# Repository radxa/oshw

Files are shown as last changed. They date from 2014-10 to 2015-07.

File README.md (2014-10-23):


Hardware design from radxa®
=========================
Hardware work from radxa including:

* Schematic in Orcad and PDF file format
* PCB file
* Gerber file
* Bill of material(BOM)

NOTE
--------
We release these hardware design file in the purpose of study and evaluation. These hardware design files, material lists etc are tested and massively produced by Radxa Limited and proven working but we can not guarantee it works under other manufacturing environment. Radxa Limited does not take responsibility of the loss or risk of using these files. It's absolutely no WARRANTY.

LICENSE
----------


These files are licensed under a [Creative Commons Attribution 4.0 International License](http://creativecommons.org/licenses/by/4.0/), you can use it for both personal and commercial usage.

Other
-------
RADXA® is registered trade mark by Radxa Limited.

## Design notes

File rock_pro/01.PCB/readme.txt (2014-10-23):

Please open the PCB file whit the PADS9.5

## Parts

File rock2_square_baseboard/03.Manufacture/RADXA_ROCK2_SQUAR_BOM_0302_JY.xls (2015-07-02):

 | RADXA_ROCK2_SQUAR Revised: Monday, January 26, 2015
 | Index Revision: 1.0
料号 | Quantity | Reference | Part | PCB Footprint | Process | 变更内容
RADXA-01 | 1 | BT1 | BAT_3V | BAT_CR1220 | SMT
RADXA-02 | 12 | CT3,CT4,CT5,CT6,C2,C21,C7,C9,C12,C75,C94,C104 | 106（C,10UF,0805） | C0805 | SMT
RADXA-04 | 4 | CT1,C1,C45,C122 | 226(C,22UF,0805) | C0805 | SMT
RADXA-05 | 20 | C5,C22,C23,C24,C25,C33,C41,C43,C44,C56,C57,C63,C65,C68,C91,C93,C98,C100,C102,C73 | 475(C,4.7UF,0603) | C0603 | SMT
RADXA-08 | 10 | C4,C17,C18,C36,C58,C60,C61,C67,C116,C32 | 105(C.1UF,0402) | C0402 | SMT
RADXA-11 | 44 | CB1,CB2,CB3,CB4,CB5,CB6,CB7,CB8,C8,CB9,C10,C11,C13,C15,C19,C20,C26,C27,C28,C31,C34,C35,C37,C40,C42,C46,C53,C59,C62,C70,C71,C72,C76,C77,C78,C92,C95,C99,C101,C103,C105,C121,C113,C119 | 104(C,100nF,0402) | C0402 | SMT
RADXA-12 | 11 | C6,C48,C49,C50,C64,C66,C69,C108,C109,C110,C111 | 103(C,10nF,0402) | C0402 | SMT
RADXA-13 | 3 | C55,C82,C84 | 8pF(C,8pF,0402) | C0402 | SMT
RADXA-15 | 1 | C120 | 102(C,1nF,0402) | C0402 | SMT
RADXA-16 | 1 | C14 | 12P(C.12pF,0402) | C0402 | SMT
RADXA-21 | 3 | C47,C51,C52 | 100pF(C,100pF,0402) | C0402 | SMT
RADXA-22 | 4 | C29,C30,C117,C118 | 22P(C,22pF,0402) | C0402 | SMT
RADXA-26 | 1 | C3 | 47pF(C,47pF,0402) | C0402 | SMT
RADXA-29 | 9 | D1,D3,D4,D5,D14,D15,D16,D17,D18 | 1N4148 | SOD523 | SMT
RADXA-30 | 1 | D8 | LED_RED | D0603 | SMT
RADXA-31 | 1 | D7 | 1N5819 | SOD123 | SMT
RADXA-32 | 2 | D13,D10 | LED_BLUE | D0603 | SMT
RADXA-33 | 1 | D9 | LED_GREEN | D0603 | SMT
RADXA-38 | 14 | ED1,ED2,ED3,ED4,ED5,ED8,ED11,ED14,ED15,ED16,ED17,ED18,ED19,ED20 | ESD9B5V LESD8D5.0CT5G | ESD0402 | SMT
RADXA-40 | 1 | F1 | FUSE_3A | 1206-A | SMT
RADXA-41 | 1 | IR1 | FT-009(红外接收头) | TO92ECB | DIP
RADXA-42 | 1 | JD1 | USB_HOST | USB-AF | DIP
RADXA-43 | 1 | J3 | AV3-8.4-14 | PJ-342D | SMT
RADXA-45 | 1 | J1 | DC_PORT | DC-44 | DIP
RADXA-46 | 1 | J2 | MICROUSB_6.4 | MICROUSB_DIP | SMT
RADXA-47 | 1 | ANT1 | SMA | SMA_WIFI | DIP
RADXA-48 | 1 | J10 | TF_SD_SOCKET | MICROSD_SLOT | SMT
RADXA-49 | 1 | J14 | CON4 | CON4 | DIP
RADXA-50 | 1 | J13 | HEADER 20x2_2.5MM | CON_40 | DIP
RADXA-53 | 1 | J4 | FPC24P0R5 | FPC24P0R5 | SMT
RADXA-54 | 1 | J9 | FPC05P6_TOP | FPC05P6 | SMT
RADXA-55 | 1 | J8 | DLT1160 | DLT1160 | DIP
RADXA-58 | 4 | L2,L10,L11,L12 | CHOKE CM14 | USB_2012_900T | SMT
RADXA-62 | 6 | FB3,FB4,L6,L8,L9,FB7 | BLM18PG181SN1 | L0603 | SMT
RADXA-67 | 4 | Q11,Q12,Q2,Q4 | MMBT3904/2N3904 | SOT-23 | SMT
RADXA-69 | 3 | Q7,Q8,Q13 | WNM2021/2SK3018 | SOT-23 | SMT
RADXA-71 | 24 | R3,R8,R11,R12,R14,R16,R18,R23,R24,R30,R36,R57,R58,R61,R66,R67,R68,R72,R137,R138,R141,R155,R47,R15 | 10K-5% | R0402 | SMT
RADXA-72 | 6 | R25,R27,R31,R139,R161,R162 | 47K-5% | R0402 | SMT
RADXA-73 | 8 | R7,R35,R111,R142,R144,R145,R146,R157 | 4.7K-5% | R0402 | SMT
RADXA-74 | 1 | R140 | 1M-5% | R0402 | SMT
RADXA-75 | 10 | R2,R9,R10,R13,R34,R69,R70,R71,R153,R156 | 100K-5% | R0402 | SMT
RADXA-76 | 5 | R19,R46,R79,R150,R163 | 1K-5% | R0402 | SMT
RADXA-77 | 9 | R33,R114,R154,R53,R54,R115,R116,R131,R133 | 680R-5% | R0402 | SMT
RADXA-78 | 2 | R87,R109 | 100R-5% | R0402 | SMT
RADXA-81 | 1 | R5 | 51K-5% | R0402 | SMT
RADXA-83 | 2 | R20,R75 | 15K-5% | R0402 | SMT
RADXA-84 | 1 | R108 | 22R-5% | R0402 | SMT
RADXA-88 | 10 | R49,R52,R62,R64,R88,R89,R99,R110,R130,R132 | 0R-5% | R0402 | SMT
RADXA-90 | 21 | R39,R40,R41,R42,R43,R44,R59,R60,R90,R91,R92,R93,R94,R95,R117,R118,R120,R122,R124,R125,R127 | 33R-5% | R0402 | SMT
RADXA-98 | 6 | R37,R38,R81,R82,R83,R84 | 1K5-5% | R0402 | SMT
RADXA-106 | 3 | R6,R135,R17 | 12K 1% | R0402 | SMT
RADXA-108 | 2 | SW2,SW3 | SW2 | SW8 | SMT
RADXA-109 | 1 | SW1 | SW_PWR | SW2 | SMT
RADXA-112 | 3 | U4,U5,U6 | TCS9708 | SOT23-5 | SMT
RADXA-113 | 1 | U7 | GL850G | SSOP28 | SMT
RADXA-118 | 1 | U2 | HYM8563 | MSOP8 | SMT
RADXA-127 | 2 | X1,X2 | 12M/20pF | SMD5032 | SMT
RADXA-129 | 1 | Y1 | 32.768K | MC_146 | SMT
RADXA-131 | 6 | ED6,ED7,ED9,ED10,ED12,ED13 | ESDP0402(0.5pF) | ESD0402 | SMT
RADXA-134 | 1 | B1 | BLM15PX181SN1 | L0402 | SMT
RADXA-135 | 1 | CON1 | MXM3_CON | MB_0207_2E_MM70 | SMT
RADXA-136 | 1 | CT2 | 100uF/16V（107，C7343 D=3.1）10% | C7343 | SMT
RADXA-137 | 2 | C38,C39 | 225(C,2.2uF,0603) 16V 10% | C0603 | SMT
RADXA-138 | 1 | C74 | 225/50V（C，2.2uF,1206）10% | C1206 | SMT
RADXA-139 | 1 | C81 | 10pF(C,10pF,0402) 50V 5% | C0402 | SMT
RADXA-140 | 6 | C85,C86,C87,C88,C89,C90 | 33pF(C,33pF,0402) 50V 5% | C0402 | SMT
RADXA-141 | 1 | C106 | 103_1KV(C,10nF,1206) 10% | C1206 | SMT
RADXA-142 | 1 | C107 | 104/50V(C,100nF,0603) 10% | C0603 | SMT
RADXA-143 | 1 | D2 | BAT54C | SOT-23 | SMT
RADXA-144 | 1 | D6 | SS34/1N5822 | DO214AC | SMT
RADXA-145 | 2 | EC1,EC2 | 47uF/6.3V 20% | C1206 | SMT
RADXA-146 | 2 | FB5,FB6 | BLM18EG601SN1 | L0603 | SMT
RADXA-147 | 2 | GU1,GU2 | TCS2108-1V8 | SOT23-5 | SMT
RADXA-148 | 1 | GU3 | TCS2108-2V8 | SOT23-5 | SMT
RADXA-149 | 1 | GU4 | TCS2108-1V5 | SOT23-5 | SMT
RADXA-150 | 1 | J5 | eDP_Flex | AJ752-B-S-51 | SMT
RADXA-151 | 1 | J6 | HDMI_A | HDMI_A | DIP
RADXA-152 | 1 | J7 | HEADER_2X25_2R0 | DUL_2X25_2R0 | DIP
RADXA-153 | 1 | J11 | SATA_7P | SATA_7PIN | DIP
RADXA-154 | 1 | J12 | CON2 | HX25002-2P | DIP
RADXA-155 | 2 | L1,L4 | SWPA4020S4R7MT/2A | IND-4X4 | SMT
RADXA-156 | 1 | L5 | SWPA3015S3R3NT/1A | IND_3X3 | SMT
RADXA-157 | 1 | MIC1 | MIC | MIC-4520 | DIP
RADXA-158 | 1 | P8 | USB-A-DULE | USB-A-DULE | DIP
RADXA-159 | 2 | Q1,Q3 | WPM2015 | SOT-23 | SMT
RADXA-160 | 2 | Q5,Q6 | WNM2016 | SOT-23 | SMT
RADXA-161 | 1 | Q9 | AO3423 | SOT-23 | SMT
RADXA-162 | 1 | R1 | 442K-1% | R0402 | SMT
RADXA-163 | 1 | R4 | 200K-5% | R0402 | SMT
RADXA-164 | 3 | R45,R56,R164 | 2K2-5% | R0402 | SMT
RADXA-165 | 2 | R50,R51 | 4R7-5% | R0402 | SMT
RADXA-166 | 2 | R73,R74 | 2R-5% | R1206 | SMT
RADXA-167 | 1 | R76 | 150K-5% | R0402 | SMT
RADXA-168 | 1 | R160 | 10R-5% | R0402 | SMT
RADXA-169 | 1 | U1 | TCS4199 | SOT23-5 | SMT
RADXA-170 | 1 | U3 | CE7533MMR/BP6212-33MMR | SOT-23 | SMT
RADXA-171 | 1 | U8 | ES8388 | WM8988 | SMT
RADXA-172 | 1 | U9 | SY7203 | QFN8-2X3 | SMT
RADXA-173 | 3 | U10,U11,U12 | TPD4E05U06/AZ1045-04F | SLP2510P8 | SMT
RADXA-174 | 1 | U14 | AP6335 | AP6335 | SMT
RADXA-175 | 1 | U15 | HFJ11-1G01E/HFJ11-1G02E | RJ45_1000M | DIP
RADXA-176 | 1 | U16 | JM20329 | LQFP48 | SMT
RADXA-177 | 2 | X3,X4 | 表贴螺母 | 3.0MM | SMT
RADXA-179 | 1 | Y2 | 37.4MHz-10ppm | CRY-D3225 | SMT
RADXA-180 | 1 |  | RADXA_ROCK2_SQUARE PCB | PCB

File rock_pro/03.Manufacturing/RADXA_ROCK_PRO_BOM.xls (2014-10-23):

RADXA_ROCK_PRO_BOM_FULL_2014 Revise 201400821
CONTENT INDEXING Revision: 2.0 FULL
Bill Of Materials June 17,2014 15:16:31 |  | Page1
Item | 料号 | Quantity | Reference | Part | PCB Footprint | Process | Changement
1 | RADXA-01 | 1 | BT1 | BAT_3V | BAT_CR1220 | SMT
2 | RADXA-02 | 15 | C1,C2,C4,C7,C12,C51,C55,C56,C78,C79,C121,C127,C167,C198,C204 | 106（C,10UF,0805） | C0805 | SMT
3 | RADXA-03 | 5 | C3,C26,C40,C44,C122 | 105(C,1UF,0603) | C0603 | SMT
4 | RADXA-04 | 8 | C5,C6,C8,C9,C11,C13,C120,C126 | 226(C,22UF,0805) | C0805 | SMT
5 | RADXA-05 | 21 | C10,C16,C20,C45,C46,C100,C101,C106,C107,C144,C151,C159,C187,C189,C192,C212,C219,C224,C226,C243,C244 | 475(C,4.7UF,0603) | C0603 | SMT
6 | RADXA-06 | 4 | C14,C175,C180,C193 | 106(C,10UF,0603) | C0603 | SMT
7 | RADXA-07 | 11 | C15,C17,C18,C19,C21,C22,C24,C25,C162,C177,C186 | 225（C,2.2UF.0402） | C0402 | SMT
8 | RADXA-08 | 17 | C23,C37,C96,C114,C128,C129,C136,C138,C141,C152,C171,C172,C181,C182,C188,C197,C241 | 105(C.1UF,0402) | C0402 | SMT
9 | RADXA-09 | 1 | C27 | 473(C,47nF,0402) | C0402 | SMT
10 | RADXA-10 | 4 | C28,C34,C39,C50 | 475(C4.7UF,0402) | C0402 | SMT
11 | RADXA-11 | 106 | C29,C30,C31,C32,C43,C47,C48,C49,C52,C53,C54,C57,C58,C59,C60,C61,C62,C63,C64,C65,C66,C67,C68,C69,C70,C71,C72,C80,C81,C82,C83,C84,C85,C86,C87,C88,C89,C90,C91,C92,C93,C94,C95,C108,C116,C117,C118,C119,C130,C131,C132,C133,C134,C135,C137,C139,C140,C142,C143,C145,C146,C147,C149,C153,C154,C155,C156,C157,C158,C160,C161,C163,C164,C173,C176,C178,C179,C183,C190,C191,C194,C195,C199,C201,C202,C208,C209,C210,C211,C213,C214,C215,C217,C218,C220,C221,C222,C225,C227,C228,C229,C230,C231,C245,C246,C247 | 104(C,100nF,0402) | C0402 | SMT
12 | RADXA-12 | 2 | C33,C38 | 103(C,10nF,0402) | C0402 | SMT
13 | RADXA-13 | 3 | C35,C36,C184 | 8pF(C,8pF,0402) | C0402 | SMT
14 | RADXA-14 | 2 | C124,C236 | 223(C,22nF,0402) | C0402 | SMT
15 | RADXA-15 | 7 | C73,C74,C75,C76,C77,C125,C148 | 102(C,1nF,0402) | C0402 | SMT
16 | RADXA-16 | 1 | C113 | 12P(C.12pF,0402) | C0402 | SMT
17 | RADXA-17 | 4 | C123,C170,C238,C239 | 104(C,100nF,0603) | C0603 | SMT
18 | RADXA-18 | 3 | C150,C165,C169 | 105/25V(C,1uF,0805) | C0805 | SMT
19 | RADXA-19 | 1 | C166 | 104/25V(C,100nF,0603) | C0603 | SMT
20 | RADXA-20 | 1 | C168 | 104/25V(C.100nF,0402) | C0402 | SMT
21 | RADXA-21 | 1 | C174 | 100pF(C,100pF,0402) | C0402 | SMT
22 | RADXA-22 | 4 | C196,C200,C41,C42 | 22P(C,22pF,0402) | C0402 | SMT
23 | RADXA-23 | 2 | C203,C240 | 101(C,0.1nF,0402) | C0402 | SMT
24 | RADXA-24 | 1 | C205 | 331(C,0.33nF,0402) | C0402 | SMT
25 | RADXA-25 | 2 | C206,C207 | 106(C,10uF,1205) | C1206 | SMT
26 | RADXA-26 | 1 | C216 | 47pF(C,47pF,0402) | C0402 | SMT
27 | RADXA-27 | 1 | C237 | 102/2KV(C,1nF,1206) | C1206 | SMT
28 | RADXA-28 | 1 | C242 | 12pF(C,12pF.0402) | C0402 | SMT
29 | RADXA-29 | 13 | D1,D2,D3,D4,D7,D10,D12,D13,D14,D15,D16,D17,D18 | 1N4148 | SOD523 | SMT
30 | RADXA-30 | 1 | D5 | LED_RED | LED0603 | SMT
31 | RADXA-31 | 6 | D6,D19,D20,D21,D26,D51 | 1N5819 | SOD123 | SMT
32 | RADXA-32 | 1 | D8 | LED_BULE | LED0603 | SMT
33 | RADXA-33 | 2 | D9,D28 | LED_GREEN | LED0603 | SMT
34 | RADXA-34 | 3 | D22,D24,D27 | BAT54S | SOT23 | SMT
35 | RADXA-35 | 1 | D23 | 6.8V（stabilivolt tube） | D1206 | SMT
36 | RADXA-36 | 1 | D25 | 20V（stabilivolt tube） | D1206 | SMT
37 | RADXA-37 | 1 | D29 | LED_YELLOW | LED0603 | SMT
38 | RADXA-38 | 32 | ED1,ED2,ED3,ED6,ED7,ED10,ED13,ED14,ED15,ED16,ED17,ED18,ED19,ED20,ED21,ED22,ED23,ED24,ED25,ED26,ED27,ED28,ED29,ED30,ED31,ED32,ED33,ED34,ED35,ED36,ED37,ED38 | ESD9B5V | SOD882 | SMT | DEL:ED4，ED5，ED8，ED9，ED11，ED12
39 | RADXA-39 | 1 | FB2 | 0R（bead） | L0603 | SMT
40 | RADXA-40 | 1 | F1 | FUSE_3A | F1206 | SMT
41 | RADXA-41 | 1 | IR1 | FT-009(IR) | IR_RECEIVE_3P | DIP
42 | RADXA-42 | 2 | JD1,JD2 | USB_HOST | USB_A | DIP
43 | RADXA-43 | 1 | JP1 | AV3-8.4-14 | PJ-342D | SMT
44 | RADXA-44 | 1 | JP2 | RJ45 | RJ45_CB | SMT
45 | RADXA-45 | 1 | J1 | DC_PORT | DC_JACK_5V2A | DIP
46 | RADXA-46 | 1 | J3 | MICROUSB_6.4 | USB_MINI_AB | SMT
47 | RADXA-47 | 1 | J4 | SMA | SMA_WIFI | DIP
48 | RADXA-48 | 1 | J5 | TF_SD_SOCKET | MICROSD_SLOT | SMT
49 | RADXA-49 | 1 | J7 | CON4 | CON4 | DIP
50 | RADXA-50 | 2 | J8,J15 | HEADER 20x2_2.5MM | CON_40 | DIP
51 | RADXA-51 | 1 | J9 | HDMI_A | HDMI_TPA_FAM | SMT
52 | RADXA-52 | 1 | J10 | FPC05P40 | FPC05P40 | SMT
53 | RADXA-53 | 1 | J11 | FPC24P0R5 | FPC24P0R5 | SMT
54 | RADXA-54 | 1 | J12 | FPC05P6_TOP | FPC05P6 | SMT
55 | RADXA-55 | 1 | J14 | DLT1160 | SPDIF | DIP
56 | RADXA-56 | 2 | L1,L4 | 2.2uH/2.7A | NR_4X4 | SMT
57 | RADXA-57 | 2 | L2,L3 | 2.2uH/1A | NR_3X3 | SMT
58 | RADXA-58 | 2 | L5,L6 | CHOKE CM14 | USB_2012_900T | SMT
59 | RADXA-59 | 4 | L8,L9,L10,L11 | WCM-2012HDMI-900T | WCM_2012HDMI_900T | SMT
60 | RADXA-60 | 2 | L12,L13 | 10uH | NR_4X4 | SMT
61 | RADXA-61 | 1 | L14 | 1.8uH | L0603 | SMT
62 | RADXA-62 | 4 | L15,L16,L23,FB1 | BLM18PG181SN1 | L0603 | SMT
63 | RADXA-63 | 1 | MK1 | MICROPHONE | MIC_4015 | DIP
64 | RADXA-64 | 1 | Q1 | A03407 | SOT23 | SMT
65 | RADXA-65 | 2 | Q2,Q14 | 2N3906 | SOT23 | SMT
66 | RADXA-66 | 3 | Q3,Q7,Q9 | SI2301 | SOT23 | SMT
67 | RADXA-67 | 3 | Q4,Q5,Q15 | 2N3904 | SOT23 | SMT | DEL:Q51
68 | RADXA-68 | 2 | Q6,Q8 | SI2302 | SOT23 | SMT
69 | RADXA-69 | 3 | Q10,Q11,Q12 | 2SK3018 | SOT23 | SMT
70 | RADXA-70 | 1 | Q13 | WPM2341 | SOT23 | SMT
71 | RADXA-71 | 30 | R1,R4,R7,R8,R11,R24,R26,R28,R32,R35,R36,R37,R38,R45,R48,R49,R53,R56,R78,R79,R117,R121,R122,R124,R127,R134,R138,R182,R194,R199 | 10K-5% | R0402 | SMT | DEL:R349，R126，ADD:127
72 | RADXA-72 | 9 | R2,R13,R14,R15,R29,R39,R46,R87,R88 | 47K-5% | R0402 | SMT | DEL:R348
73 | RADXA-73 | 15 | R3,R41,R55,R70,R89,R92,R95,R131,R167,R168,R174,R200,R202,R203,R205 | 4K7-5% | R0402 | SMT
74 | RADXA-74 | 9 | R5,R19,R20,R42,R50,R110,R149,R169,R170 | 1M-5% | R0402 | SMT
75 | RADXA-75 | 10 | R6,R12,R25,R54,R68,R111,R112,R119,R130,R148 | 100K-5% | R0402 | SMT | DEL:R350
76 | RADXA-76 | 6 | R9,R69,R100,R120,R129,R172 | 1K-5% | R0402 | SMT
77 | RADXA-77 | 2 | R10,R51 | 680R-5% | R0402 | SMT
78 | RADXA-78 | 4 | R16,R22,R23,R62 | 100R-5% | R0402 | SMT
79 | RADXA-79 | 1 | R17 | 4.99K-5% | R0402 | SMT
80 | RADXA-80 | 1 | R18 | 20K-5% | R0402 | SMT
81 | RADXA-81 | 1 | R21 | 51K-5% | R0402 | SMT
82 | RADXA-82 | 2 | R27,R31 | 200R-5% | R0402 | SMT
83 | RADXA-83 | 1 | R33 | 15K-5% | R0402 | SMT
84 | RADXA-84 | 19 | R43,R52,R66,R144,R145,R154,R161,R162,R175,R177,R178,R179,R180,R181,R183,R184,R186,R187,R188 | 22R-5% | R0402 | SMT
85 | RADXA-85 | 5 | R57,R58,R59,R60,R61 | 240R-%1 | R0402 | SMT
86 | RADXA-86 | 2 | R63,R64 | 10K-%1 | R0402 | SMT
87 | RADXA-87 | 1 | R75 | 0R-5% | R0603 | SMT
88 | RADXA-88 | 10 | R76,R97,R141,R151,R155,R171,R314,R364,C223,L7 | 0R-5% | R0402 | SMT
89 | RADXA-89 | 15 | R80,R81,R82,R83,R84,R85,R90,R93,R96,R98,R102,R165,R166,R173,R204 | 2K-5% | R0402 | SMT
90 | RADXA-90 | 5 | R99,R103,R156,R157,R158 | 33R-5% | R0402 | SMT
91 | RADXA-91 | 1 | R101 | 4.7K-5% | R0402 | SMT
92 | RADXA-92 | 1 | R108 | 12K-5% | R0402 | SMT
93 | RADXA-93 | 1 | R109 | 82K-5% | R0402 | SMT
94 | RADXA-94 | 2 | R113,R114 | 330K-5% | R0402 | SMT
95 | RADXA-95 | 1 | R115 | 2.2R-1% | R0805 | SMT
96 | RADXA-96 | 3 | R132,R135,R367 | 6.8K-1% | R0402 | SMT
97 | RADXA-97 | 2 | R136,R137 | 56K-1% | R0402 | SMT
98 | RADXA-98 | 4 | R139,R140,R146,R147 | 1K5-5% | R0402 | SMT
99 | RADXA-99 | 1 | R150 | 30K-5% | R0402 | SMT
100 | RADXA-100 | 2 | R152,R153 | 62K-5% | R0402 | SMT
101 | RADXA-101 | 1 | R159 | 510R-5% | R0402 | SMT
102 | RADXA-102 | 1 | R160 | 75R-1% | R0402 | SMT
103 | RADXA-103 | 4 | R163,R164,R185,R193 | 470R-5% | R0402 | SMT
104 | RADXA-104 | 4 | R189,R190,R191,R192 | 49R9-%1 | R0402 | SMT
105 | RADXA-105 | 4 | R195,R196,R197,R198 | 75R-%1 | R0603 | SMT
106 | RADXA-106 | 1 | R201 | 12K1-%1 | R0402 | SMT
107 | RADXA-107 | 1 | R394 | 8K2-1% | R0402 | SMT
108 | RADXA-108 | 2 | SW1,SW3 | SW2 | SW2 | SMT
109 | RADXA-109 | 1 | SW2 | SW_PWR | SW2 | DIP
110 | RADXA-110 | 1 | U1 | ACT8846QM460 | QFN48 | SMT
111 | RADXA-111 | 1 | U2 | RK3188 | BGA453-19X19 | SMT
112 | RADXA-112 | 3 | U3,U4,U5 | TCS9708 | SOT23-5 | SMT
113 | RADXA-113 | 1 | U7 | GL850G | SSOP28 | SMT
114 | RADXA-114 | 4 | U8,U9,U10,U11 | H5TQ4G63AFRPBC | FBGA96-10X14 | SMT
115 | RADXA-115 | 1 | U12 | RL-UM12BS-8188EUS | WIFI_BT_R | SMT
116 | RADXA-116 | 1 | U13 | TCS2108-3V3 | SOT23-5 | SMT
117 | RADXA-117 | 1 | U14 | 29F64G08CBABA | TSOP48 | SMT
118 | RADXA-118 | 1 | U17 | HYM8563 | MSOP8 | SMT
119 | RADXA-119 | 1 | U18 | RK610&616-G | RK616_BGA144 | SMT
120 | RADXA-120 | 1 | U19 | MP1488/UP6003AMT6 | SOT23-6 | SMT
121 | RADXA-121 | 1 | U20 | PT5110_2.5V | SOT23 | SMT
122 | RADXA-122 | 1 | U21 | TCS3358 | SOT23-6 | SMT
123 | RADXA-123 | 0 |  | TCS8642B/PT5305N_DS | MSOP8 | SMT
124 | RADXA-124 | 1 | U23 | RK1000_S | LQFN64_RK1000 | SMT
125 | RADXA-125 | 1 | U24 | TRC41604NL | TRC41604NL | SMT
126 | RADXA-126 | 1 | U25 | LAN8720A | LAN8270A | SMT
127 | RADXA-127 | 1 | X1 | 12M/20pF | SMD5032 | SMT
128 | RADXA-128 | 1 | Y1 | 24M-20ppm | CRY3225_M | SMT
129 | RADXA-129 | 1 | Y2 | 32.768K | MC-146 | SMT
130 | RADXA-130 | 1 |  | PCB | PCB | SMT
131 | RADXA-131 | 6 | ED4，ED5，ED8，ED9，ED11，ED12 | ESDP0402(0.5pF) | ESD0402 | SMT | NEW

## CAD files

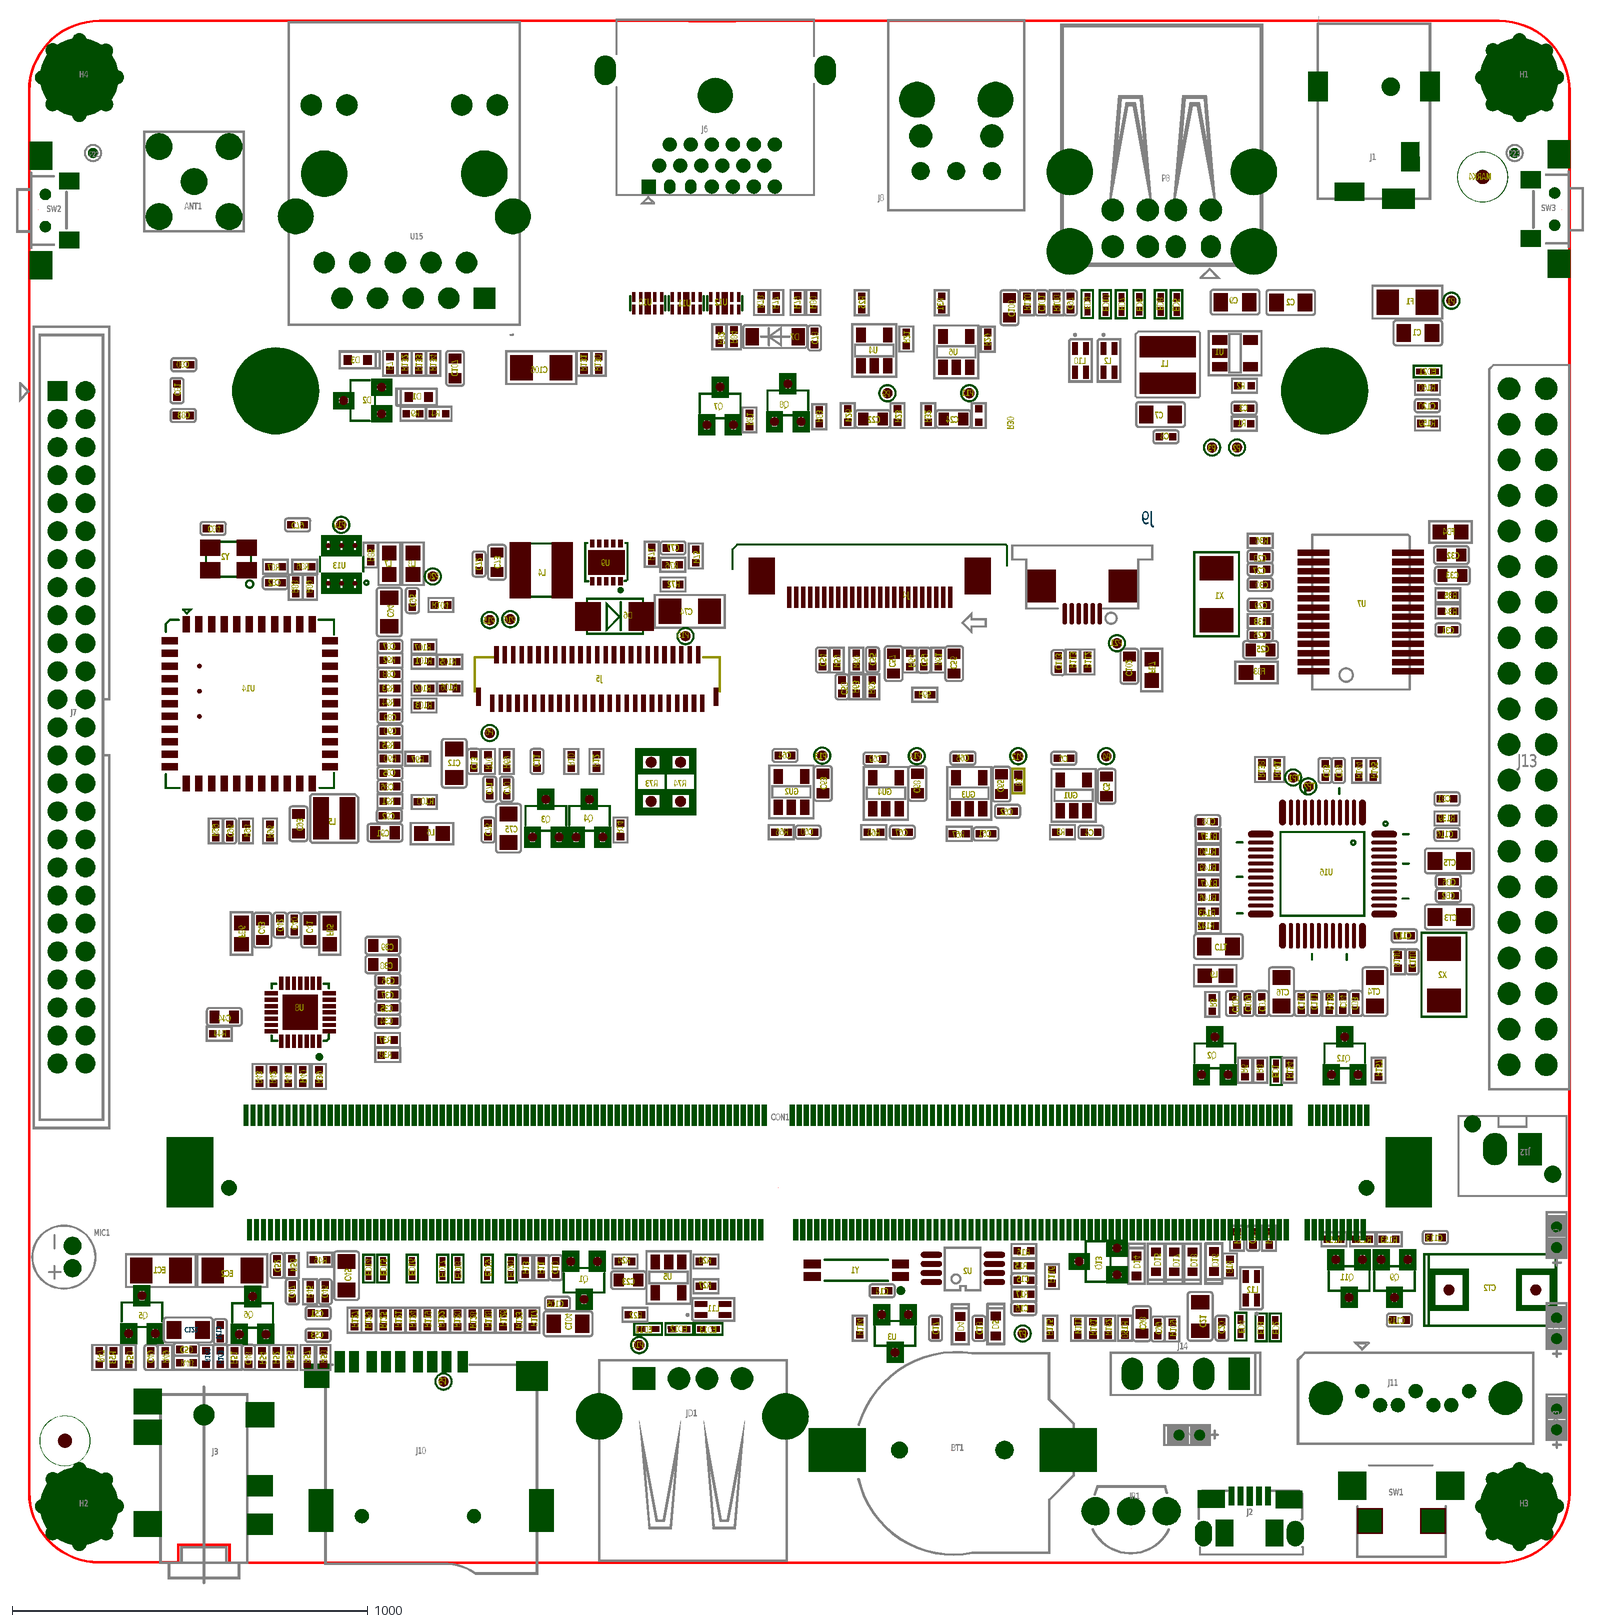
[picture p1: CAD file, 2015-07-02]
rock2_square_baseboard/02.DXF/RADXA_ROCK2_SQUARE_beta.dxf
ANT1
B1
BT1
C1
C10
C100
C101
C102
C103
C105
C106
C107
C108
C109
C11
C110
C111
C113
C116
C117
C118
C119
C120
C13
C14
C15
C16
C17
C18
C19
C2
C20
C21
C22
C23
C24
C25
C26
C27
C28
C29
C3
C30
C31
C32
C33
C34
C35
C36
C37
C38
C39
C4
C40
C41
C42
C43
C44
C45
C46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

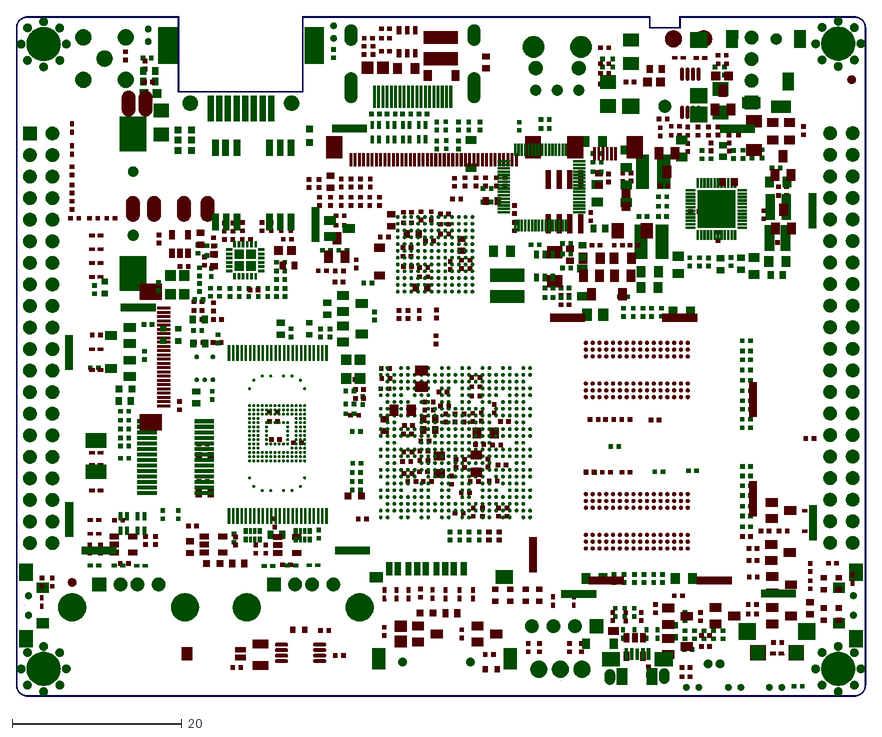
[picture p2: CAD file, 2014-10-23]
rock_pro/02.DXF/radxa_rock_pro.dxf
100.2 x 80.2

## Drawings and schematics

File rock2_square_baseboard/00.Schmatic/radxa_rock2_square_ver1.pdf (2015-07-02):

# 01.Index 02.Change List

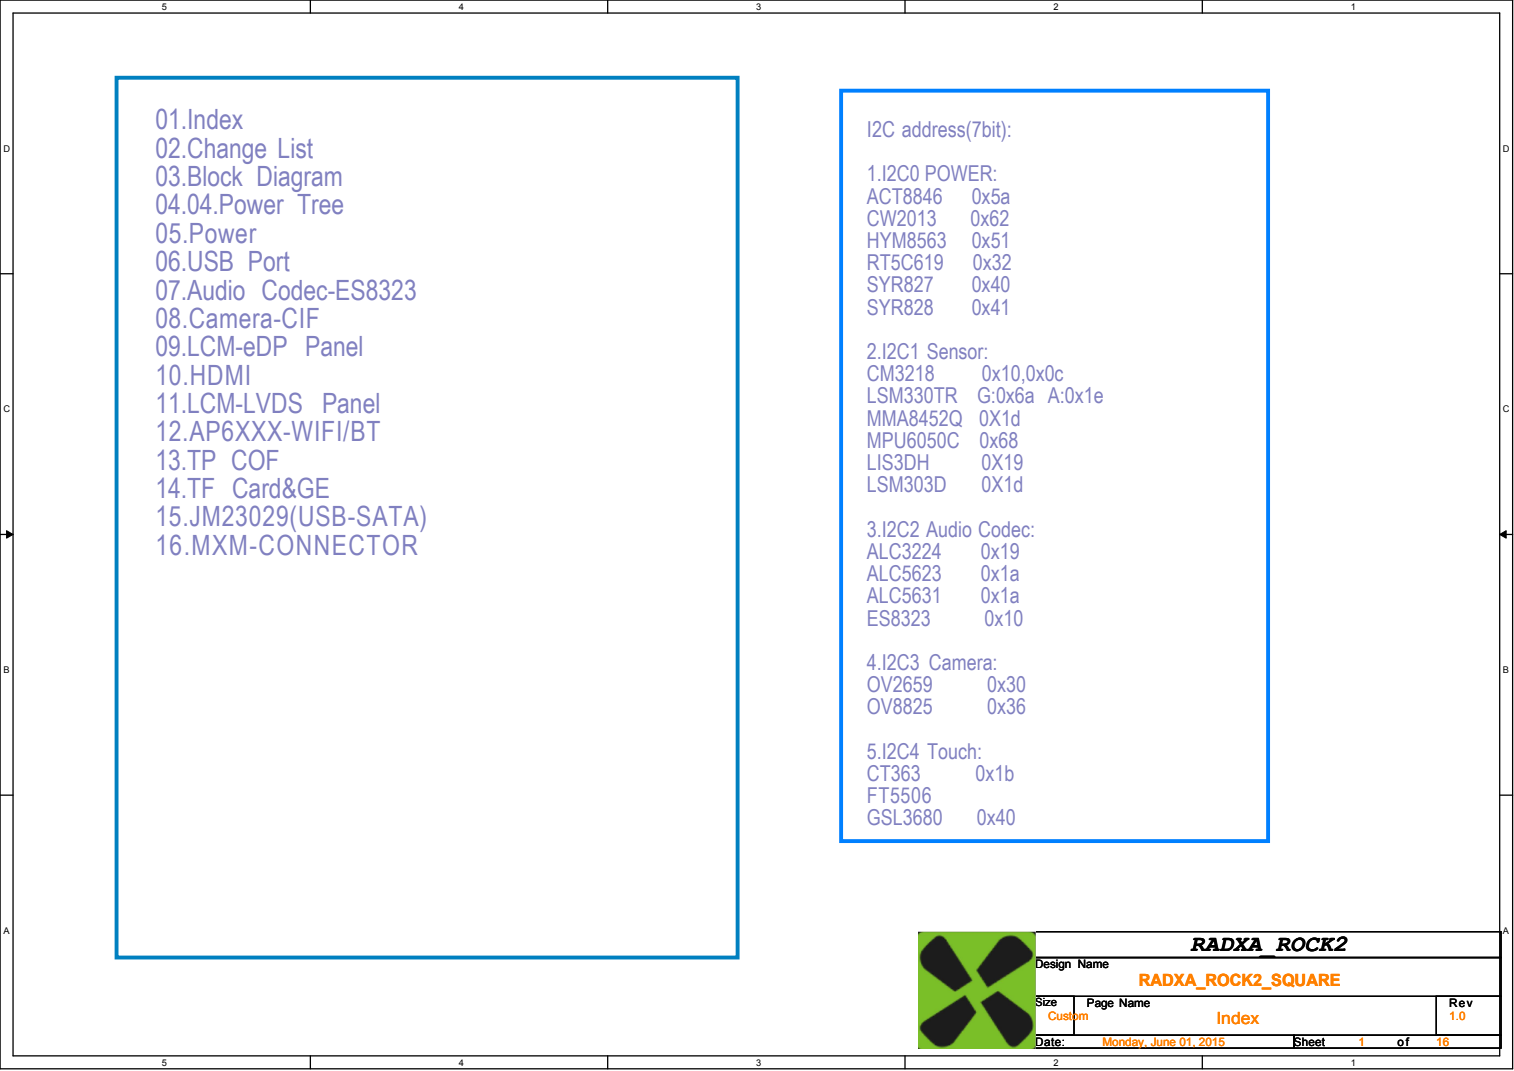
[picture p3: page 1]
I2C address(7bit):; 1.I2C0 POWER:; ACT8846; HYM8563; SYR827; SYR828; 2.I2C1 Sensor:; LSM330TR G:0x6a A:0x1e MMA8452Q 0X1d MPU6050C 0x68; LIS3DH; LSM303D; 3.I2C2 Audio Codec:; ALC3224; ALC5623; ALC5631; 4.I2C3 Camera:; 5.I2C4 Touch:; GSL3680; Design Name; Size; Page Name; Rev; Date:; Sheet; RADXA_ROCK2; Index; RADXA_ROCK2_SQUARE; Custom; Monday, June 01, 2015

03.Block Diagram
04.04.Power Tree
05.Power
06.USB Port
07.Audio Codec-ES8323
08.Camera-CIF
09.LCM-eDP Panel
10.HDMI
11.LCM-LVDS Panel
12.AP6XXX-WIFI/BT
13.TP COF
14.TF Card&GE
15.JM23029(USB-SATA)
16.MXM-CONNECTOR

# Version

V1.0 | 20140930 | Prince | First edictor | Prince

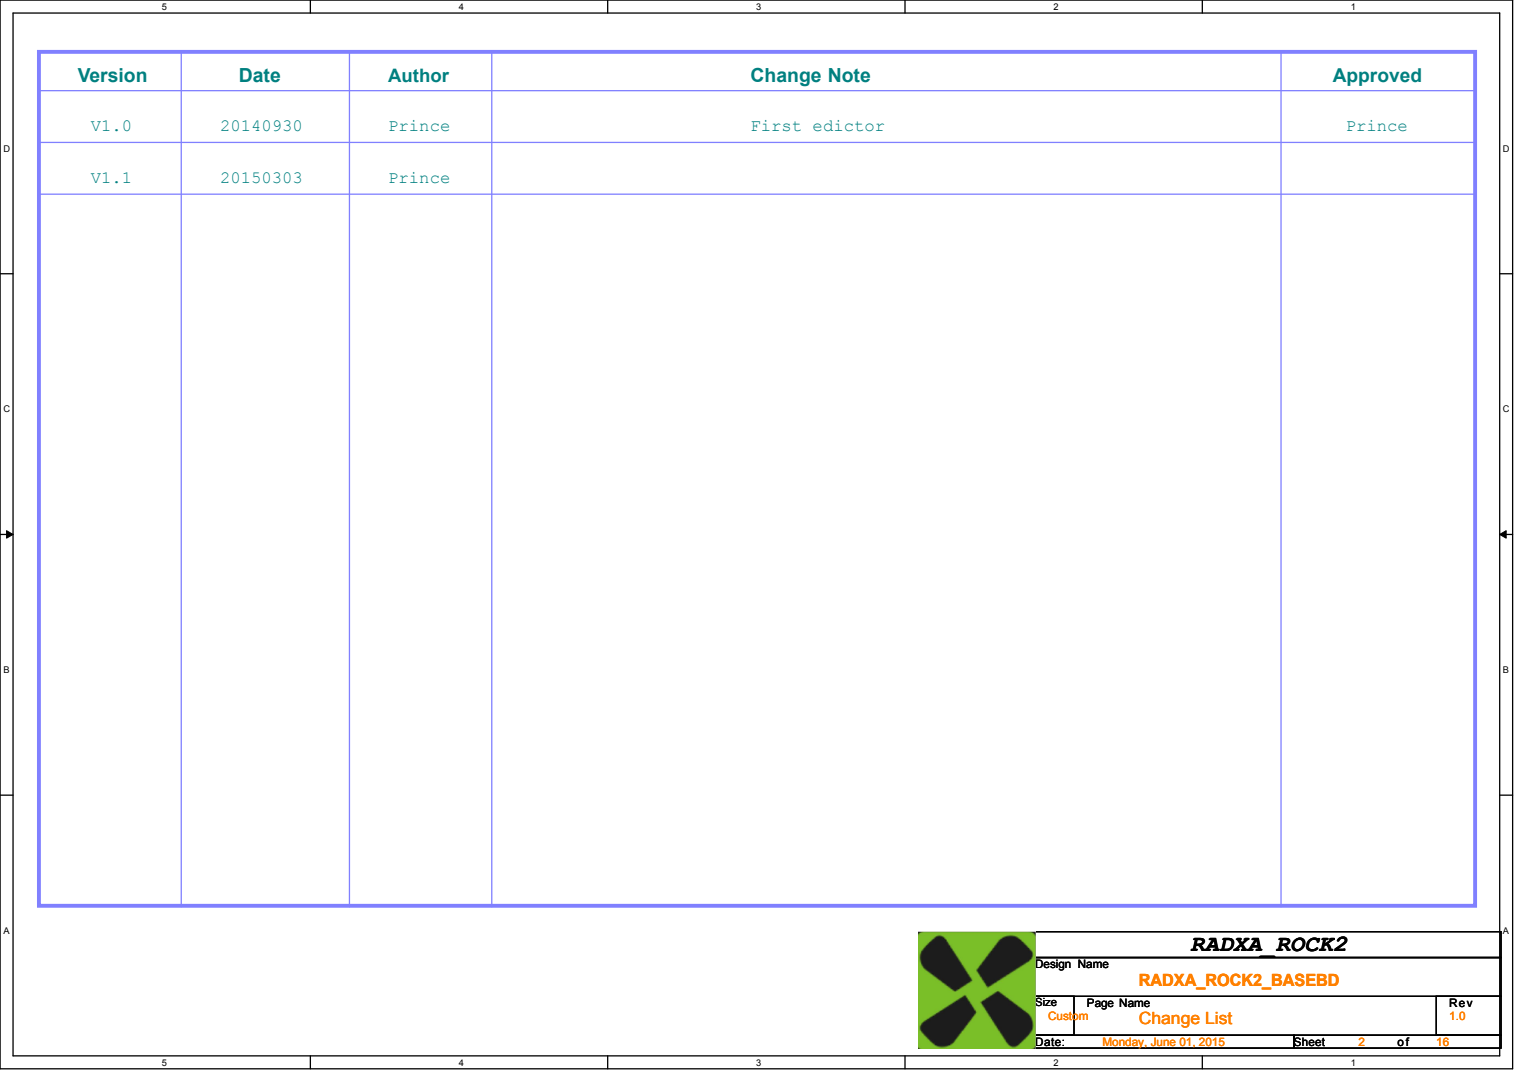
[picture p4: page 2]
Date; Author; Change Note; Approved; Prince; Design Name; RADXA_ROCK2; Change List; RADXA_ROCK2_BASEBD; Monday, June 01, 2015

# Over-

I2C0 | LVDS

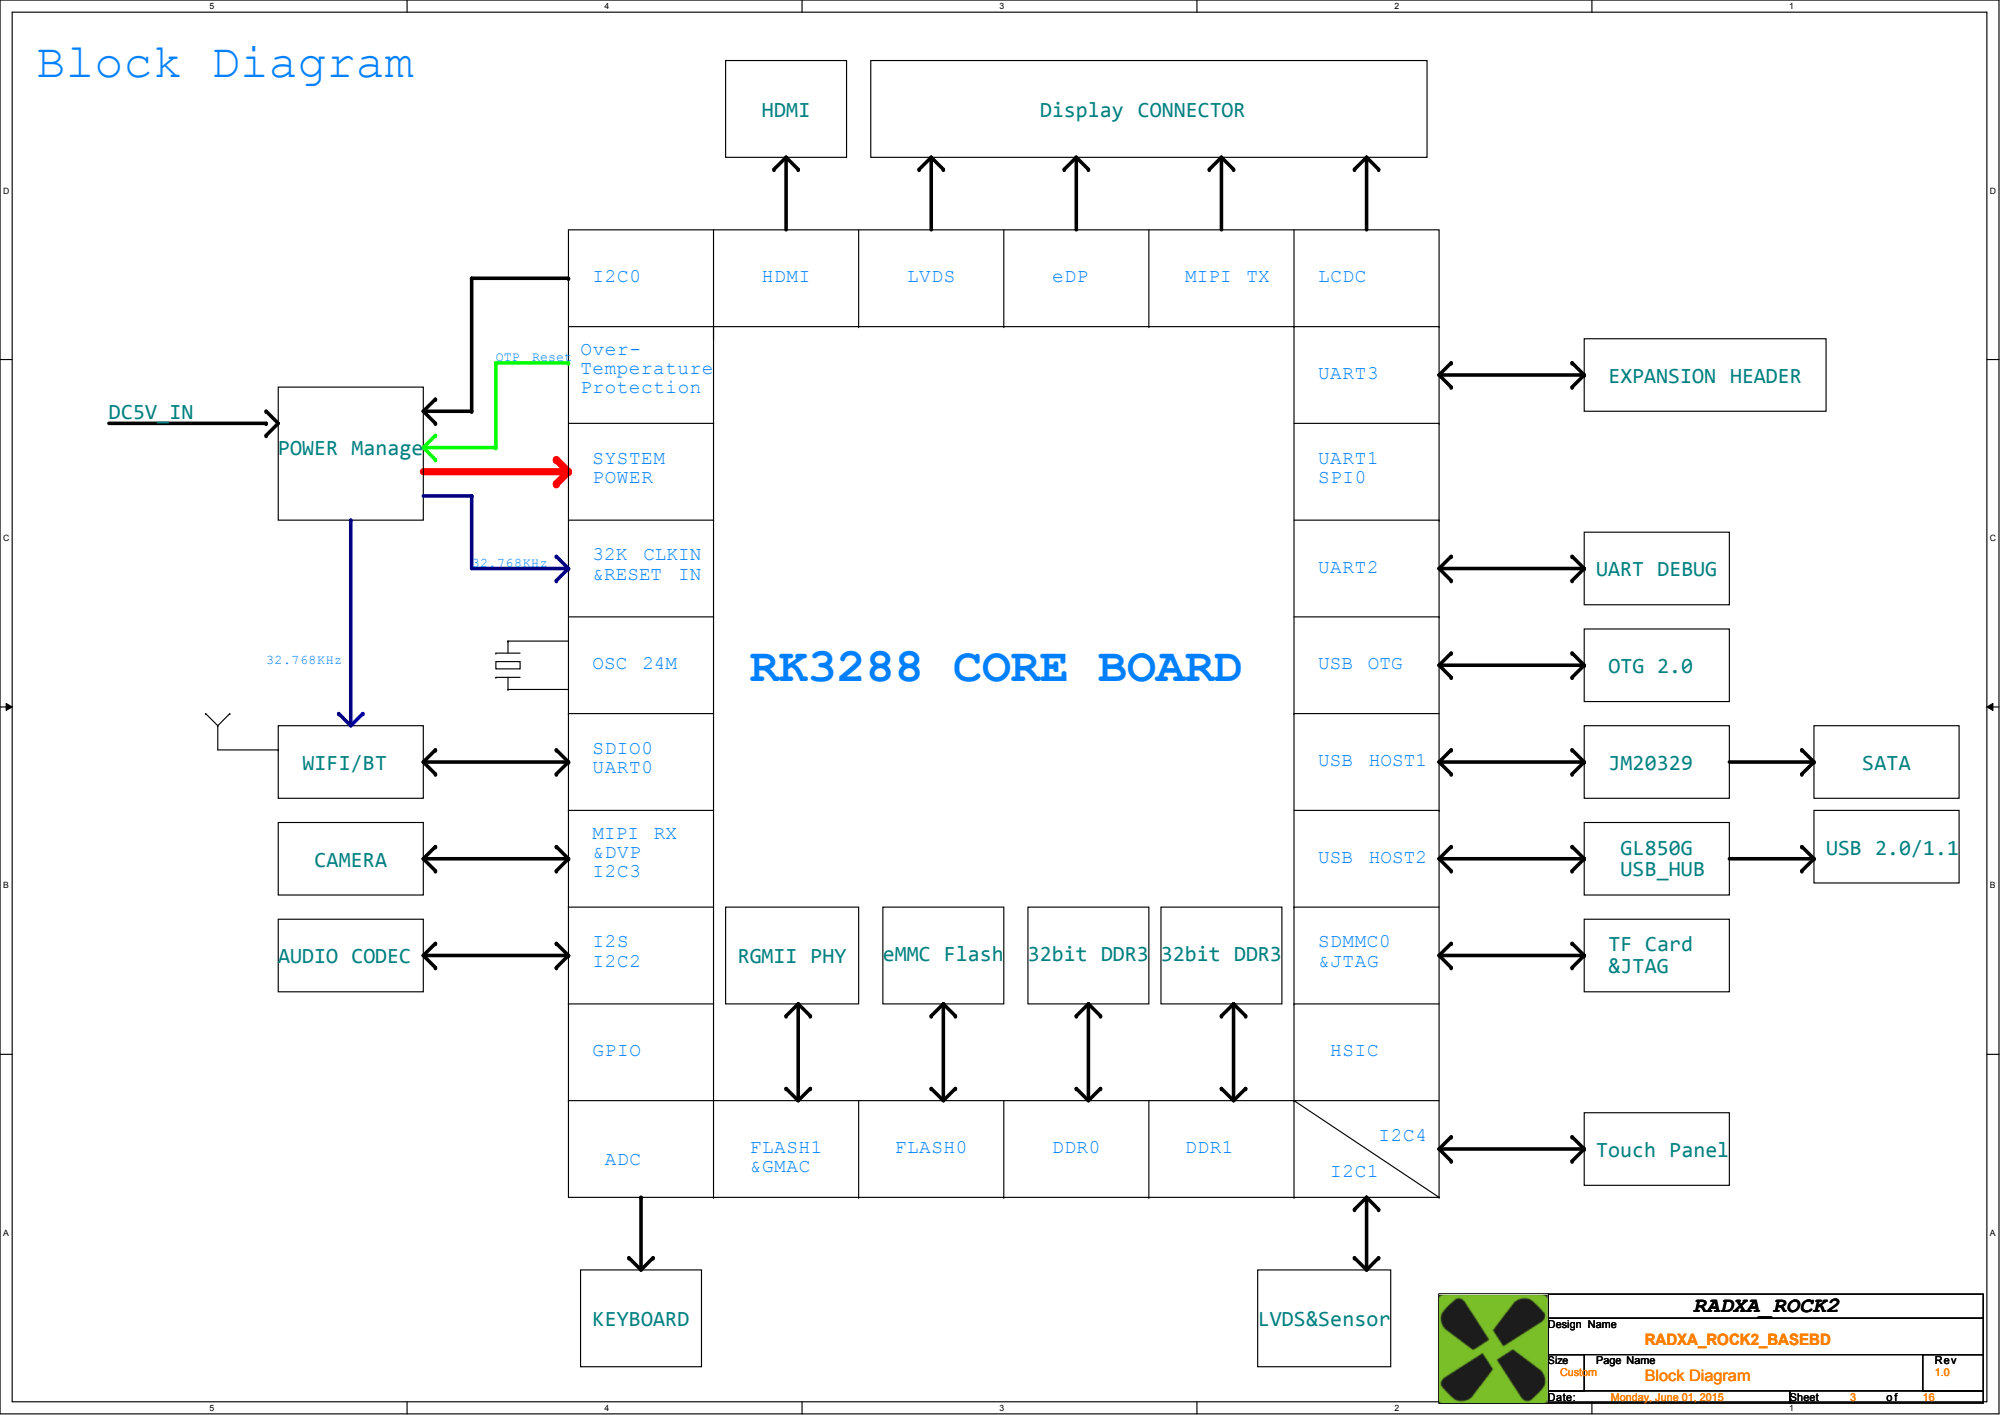
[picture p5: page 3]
UART3; FLASH0; ADC; SYSTEM POWER; RK3288 CORE BOARD; FLASH1 &GMAC; Temperature Protection; SDMMC0 &JTAG; DDR0; DDR1; 32K CLKIN &RESET IN; SDIO0 UART0; 32.768KHz; OTP Reset; GPIO; Block Diagram; MIPI RX &DVP I2C3; EXPANSION HEADER; USB HOST2; USB OTG; USB HOST1; UART2; UART1 SPI0; HDMI; eDP; MIPI TX; OSC 24M; HSIC; LCDC; UART DEBUG; OTG 2.0; GL850G USB_HUB; TF Card &JTAG; USB 2.0/1.1; Touch Panel; SATA; LVDS&Sensor; RGMII PHY; eMMC Flash; 32bit DDR3 32bit DDR3; KEYBOARD; AUDIO CODEC; CAMERA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

# VCC_SYS

DC

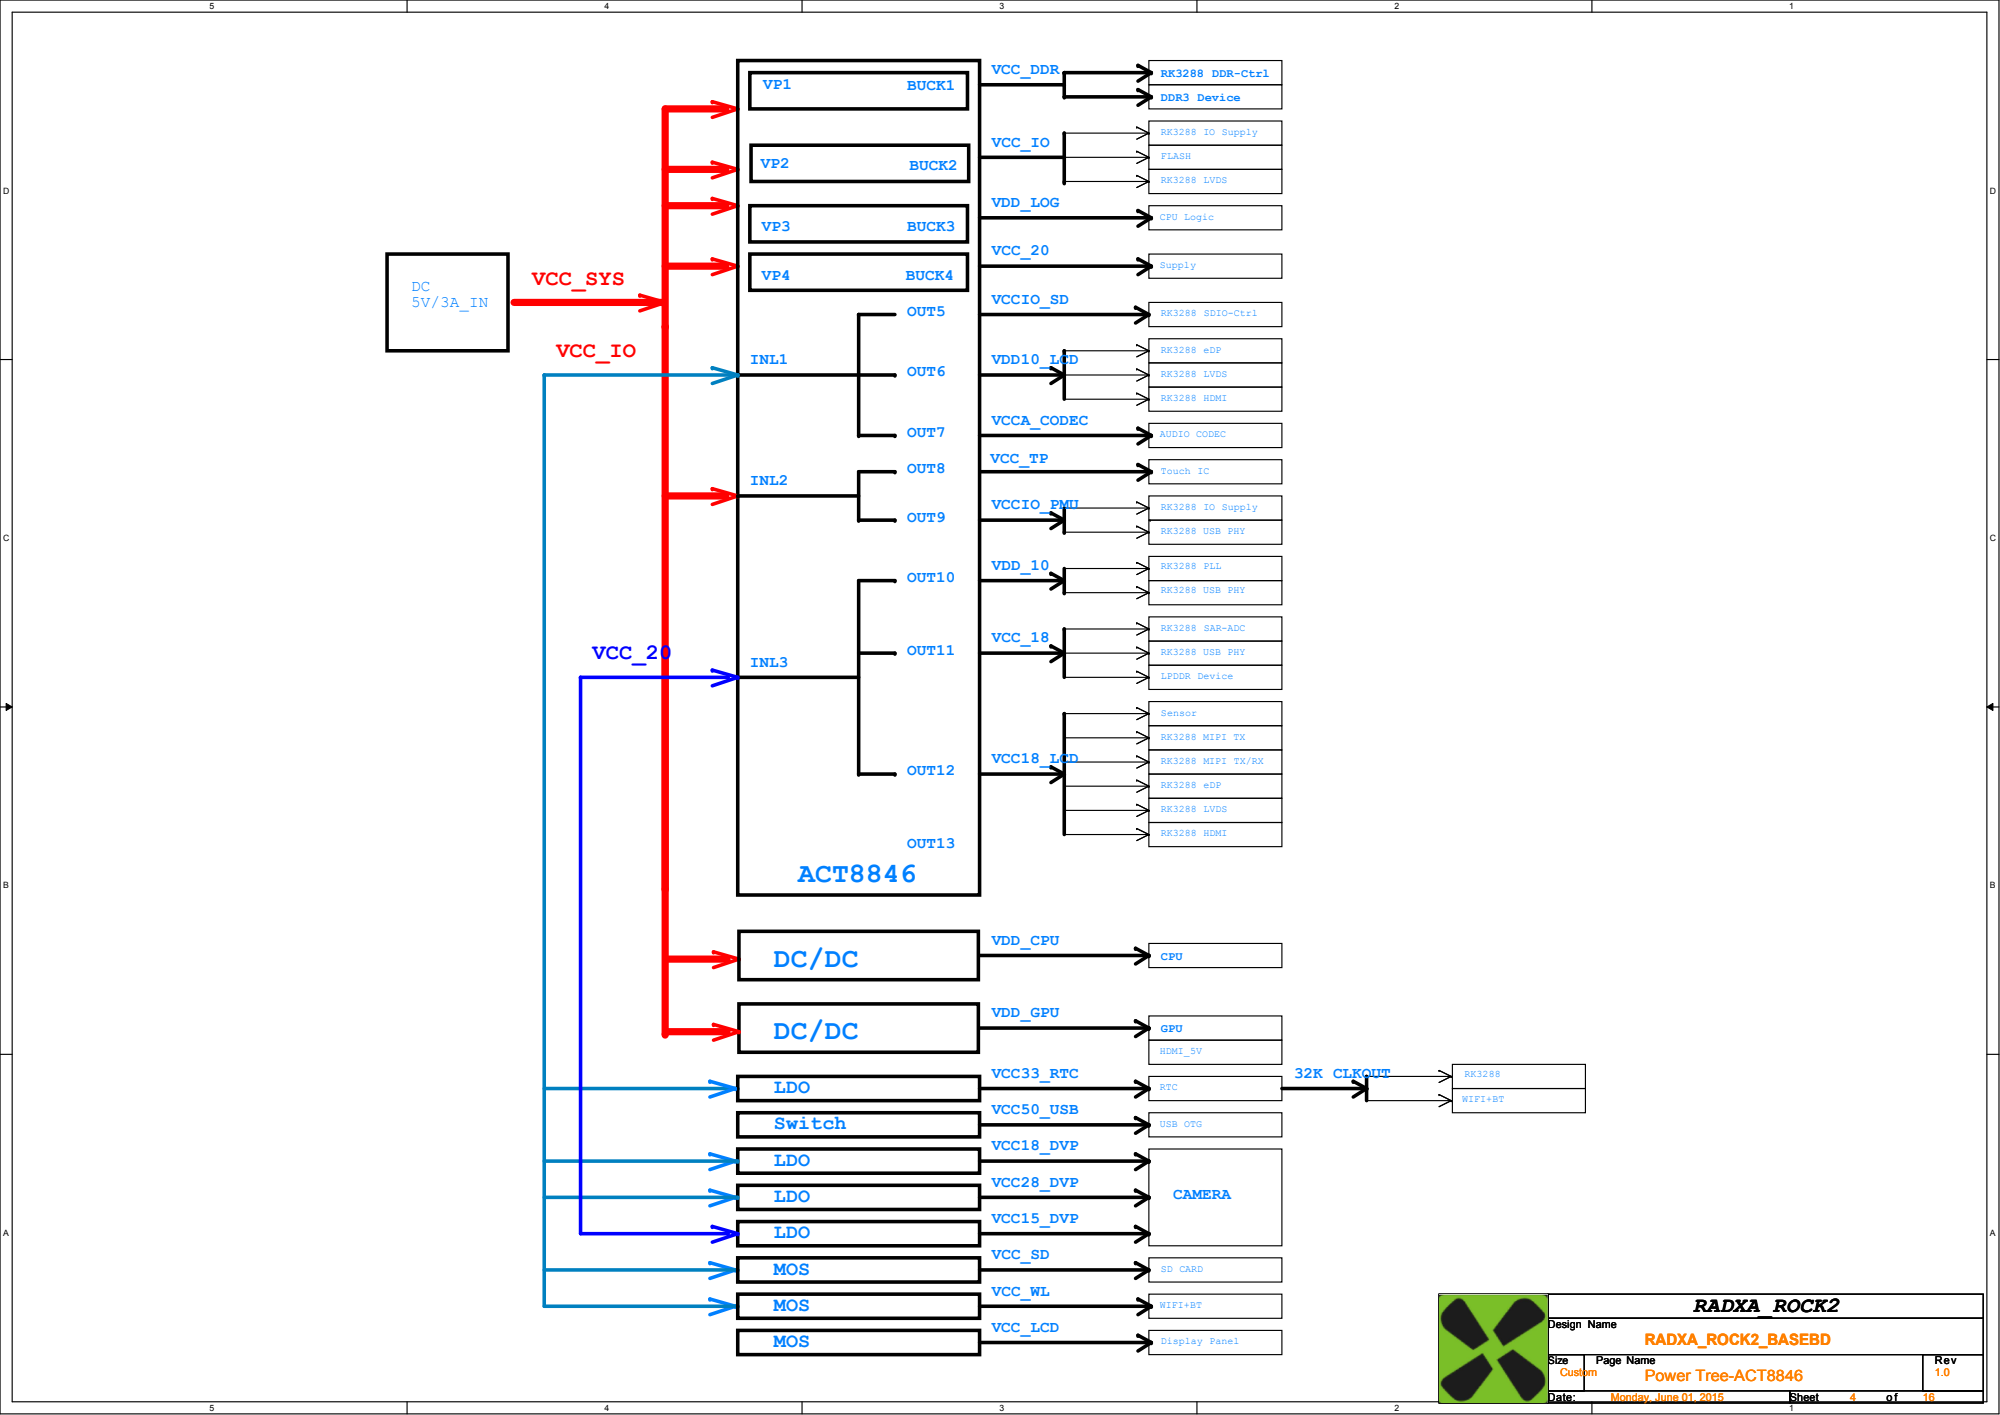
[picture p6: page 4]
VCC18_DVP; ACT8846; LDO; VCC15_DVP; CAMERA; VCC28_DVP LDO; VCC33_RTC LDO; HDMI_5V; CPU; VDD_CPU; GPU; VDD_GPU; DDR3 Device; VCC_DDR; RK3288 DDR-Ctrl; RK3288 LVDS; FLASH; RK3288 IO Supply; VCC_IO; VDD_LOG; CPU Logic; BUCK1; BUCK2; OUT5; INL2; OUT12; INL3; OUT6; OUT7; OUT8; OUT9; OUT10; OUT11; INL1 VCC_IO; VCC_20; VCC50_USB Switch; USB OTG; 32K CLKOUT; RTC; WIFI+BT; VCC_WL; SD CARD; VCC_SD MOS; MOS; VCC_LCD MOS; Display Panel; BUCK3; BUCK4; Supply; VCCIO_SD; RK3288 SDIO-Ctrl; RK3288 HDMI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

RK3288 MIPI TX/RX

VCC-3V | Vout = 0.6*(1+R1/R2)
R1 | R2

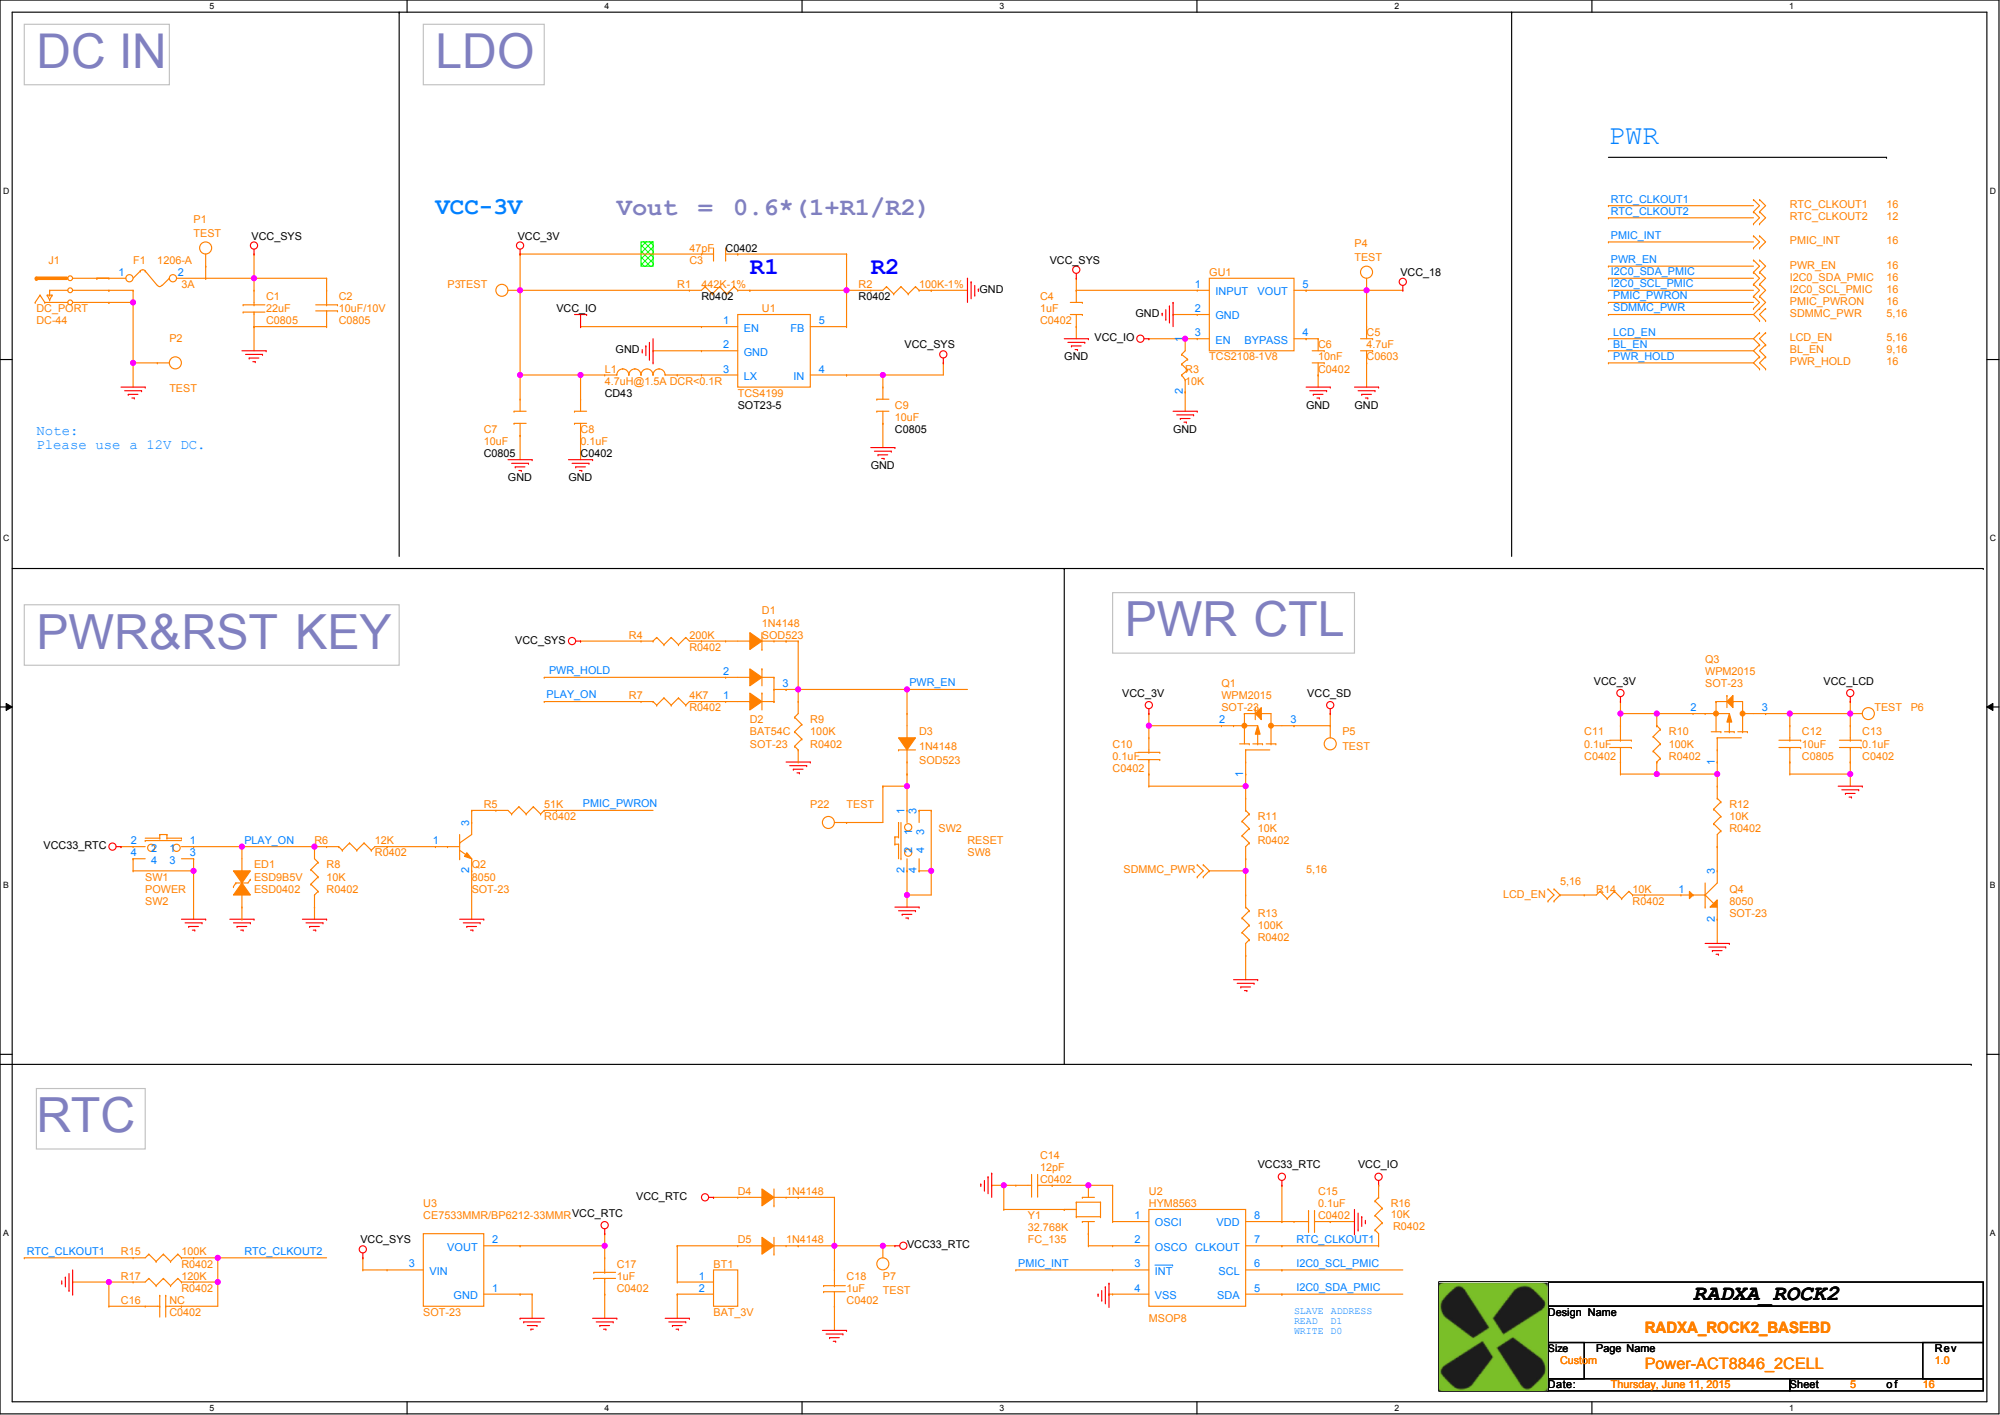
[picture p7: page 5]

# USB OTG

# USB

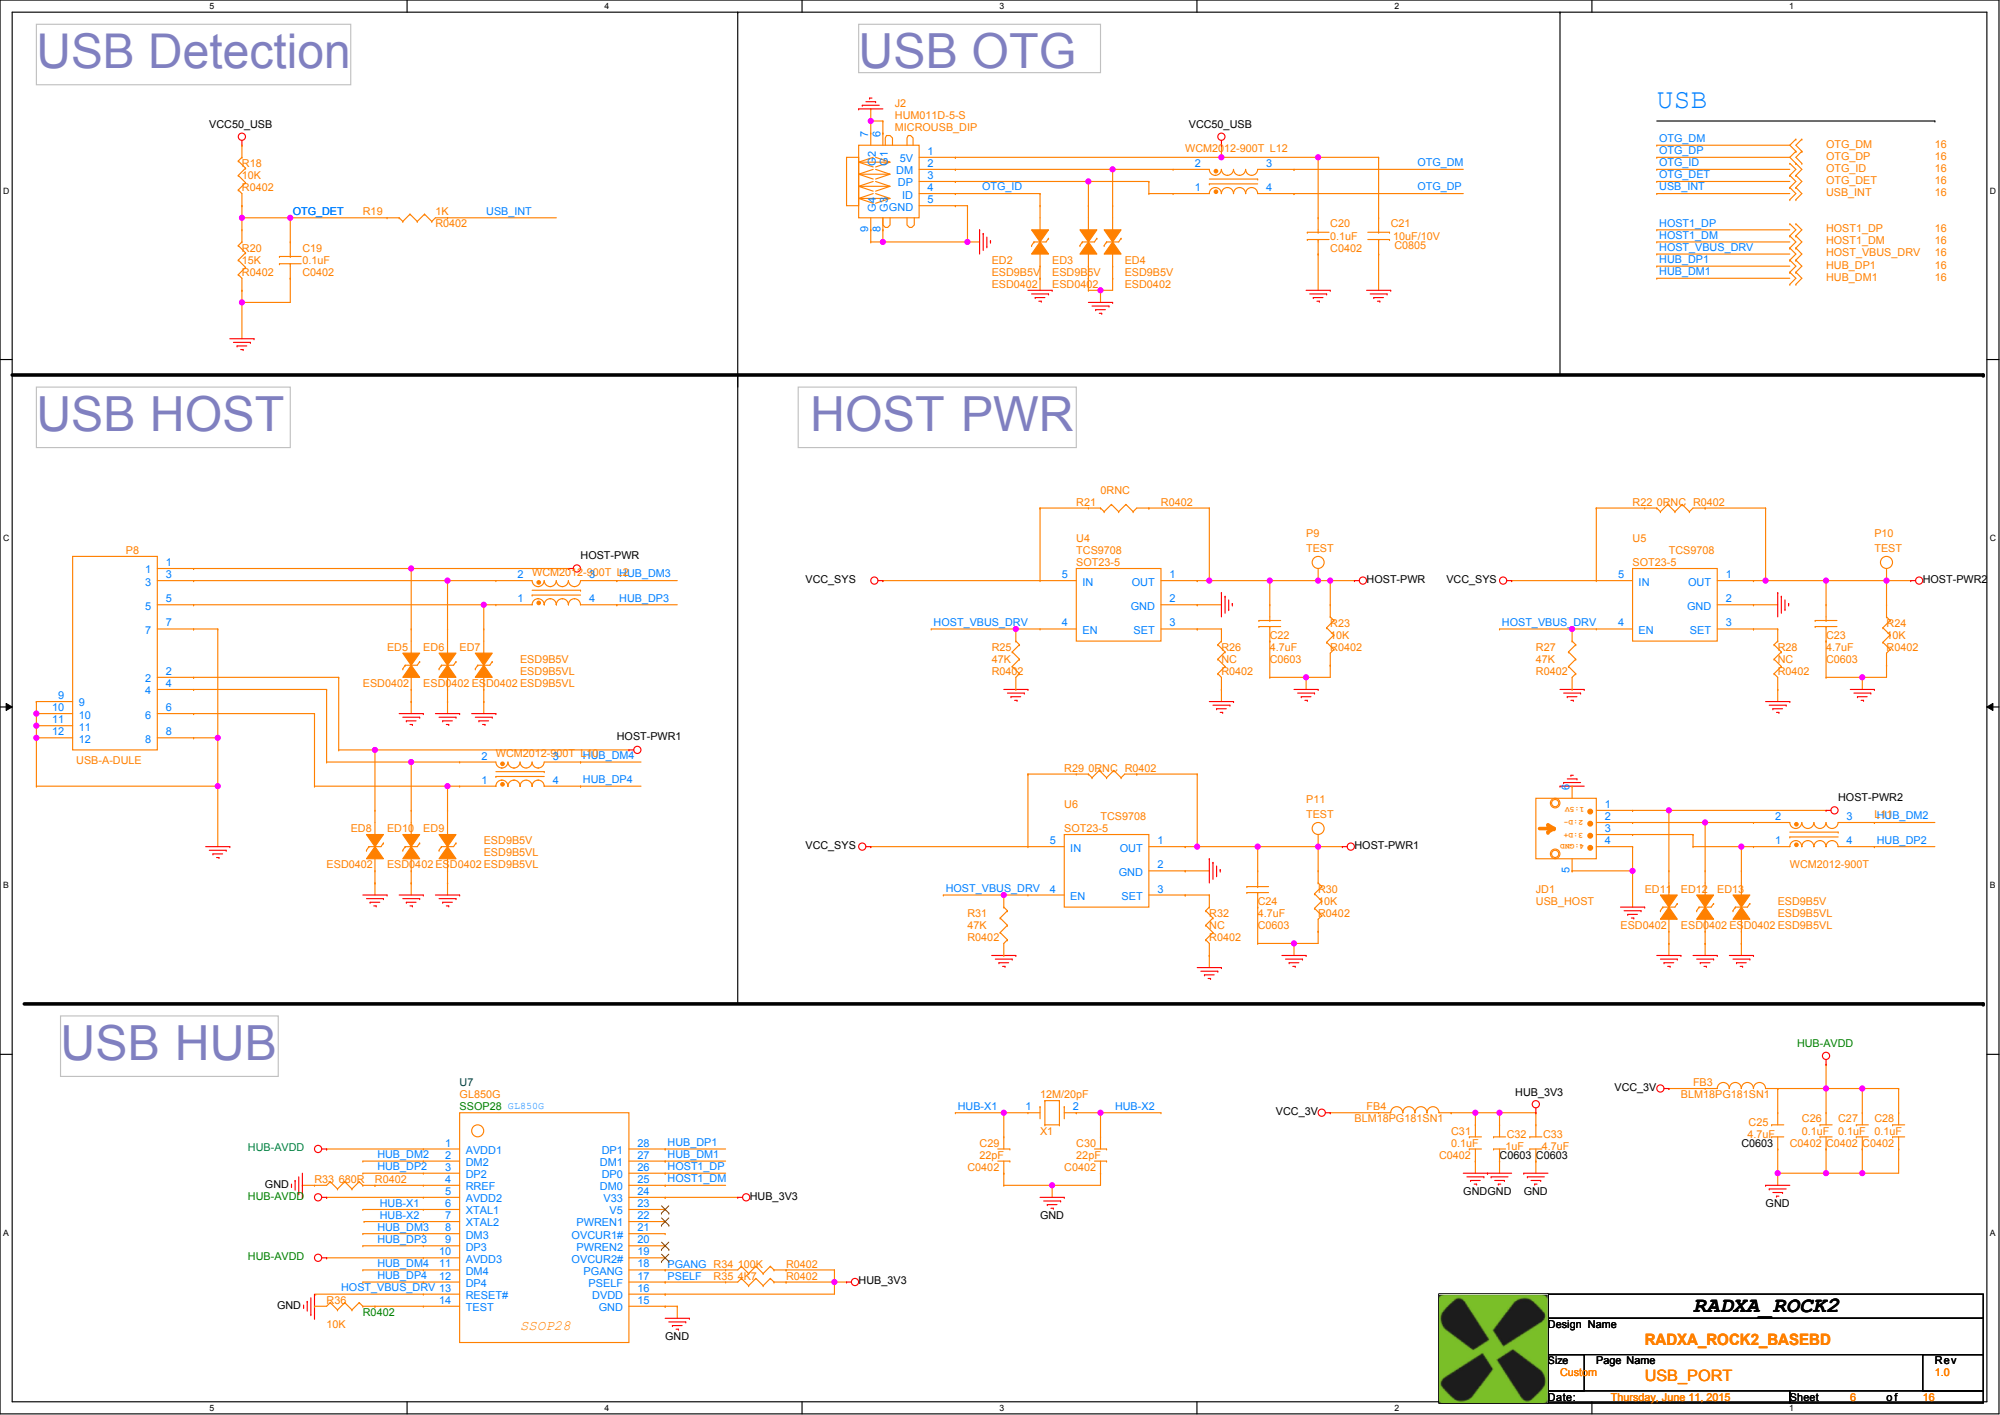
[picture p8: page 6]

## close to ES8323

## Pull up on baseboard

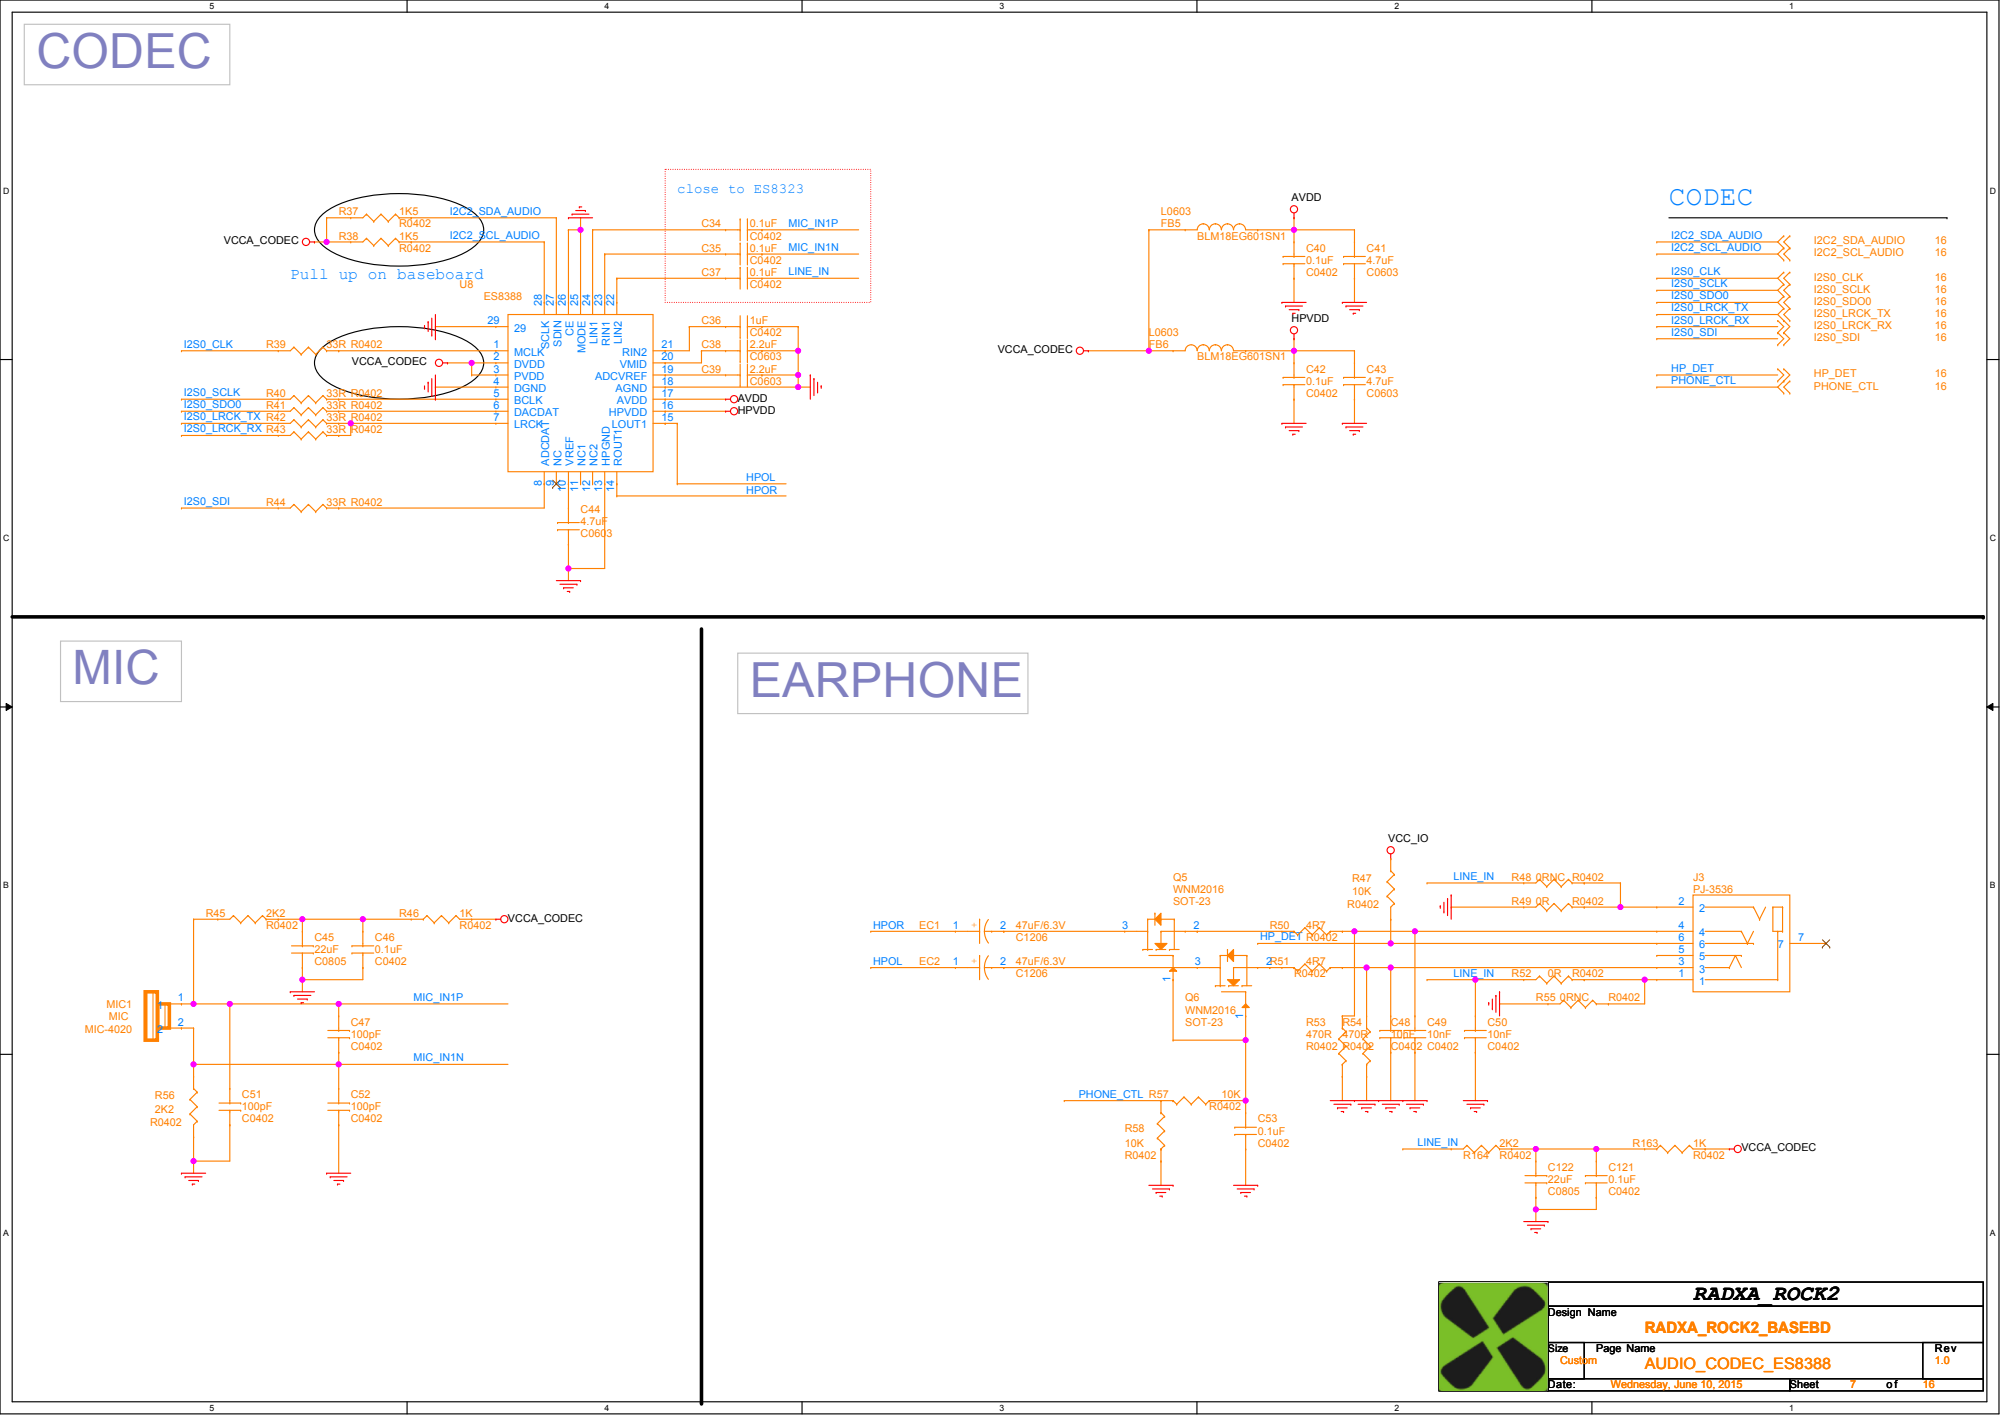
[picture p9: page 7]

# CIF Camera

## CIF_RST

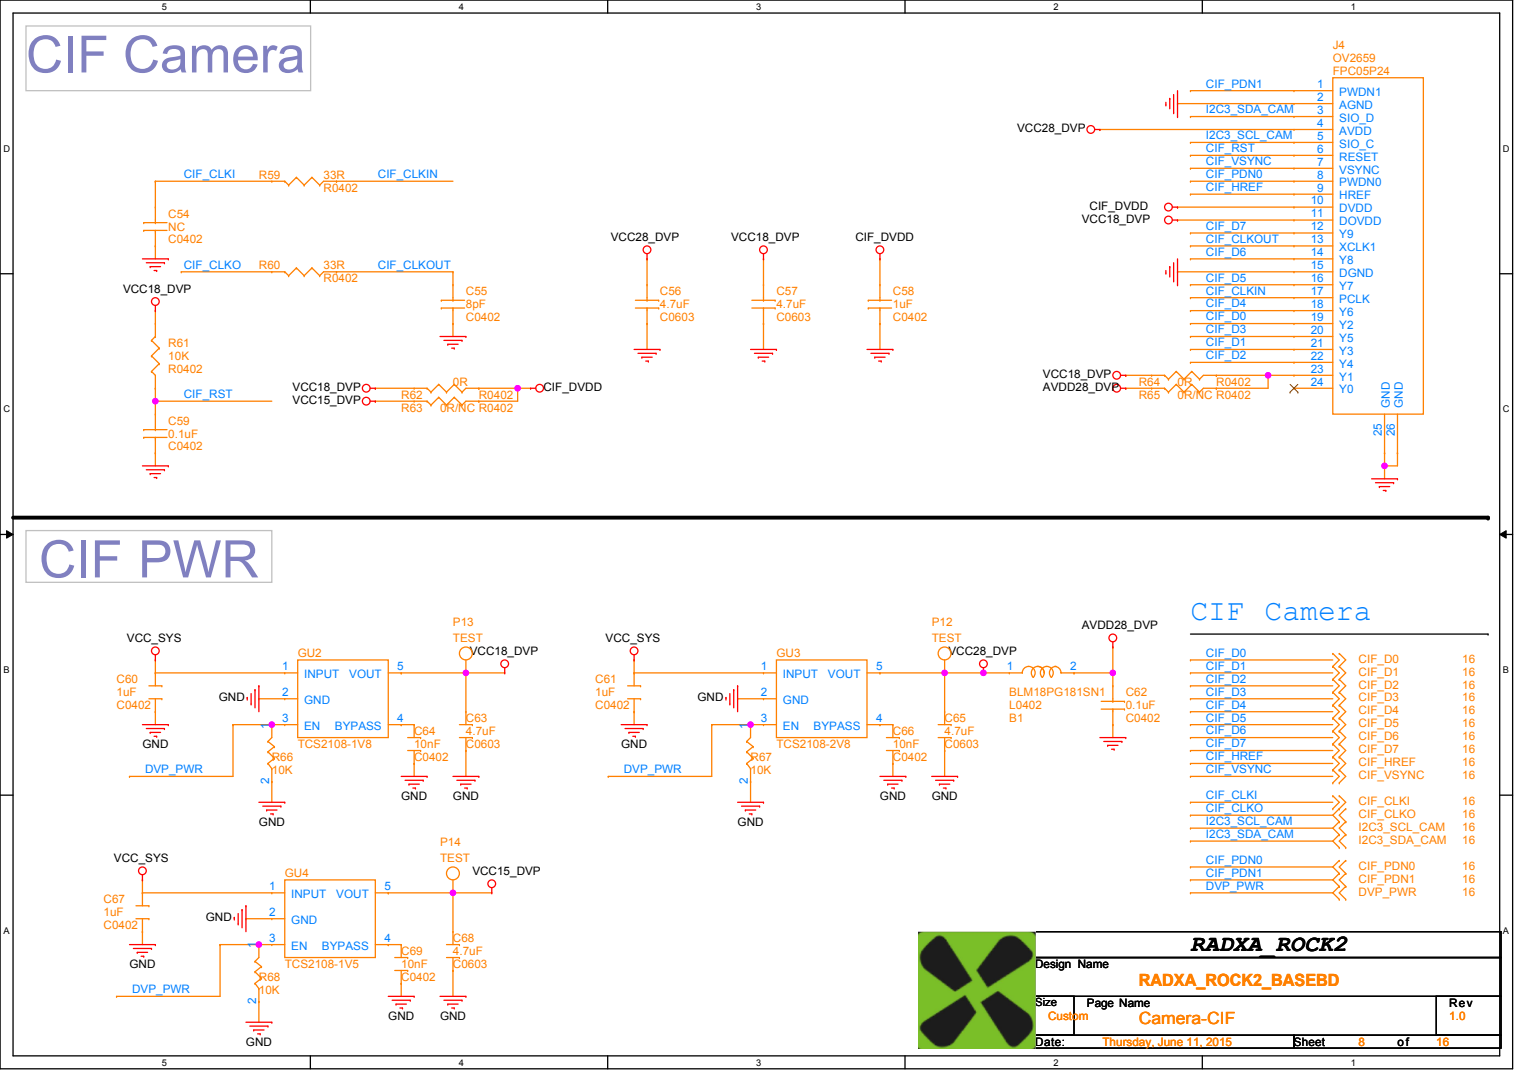
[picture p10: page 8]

# eDP Panel

EDPAUXP | EDP_AUXP

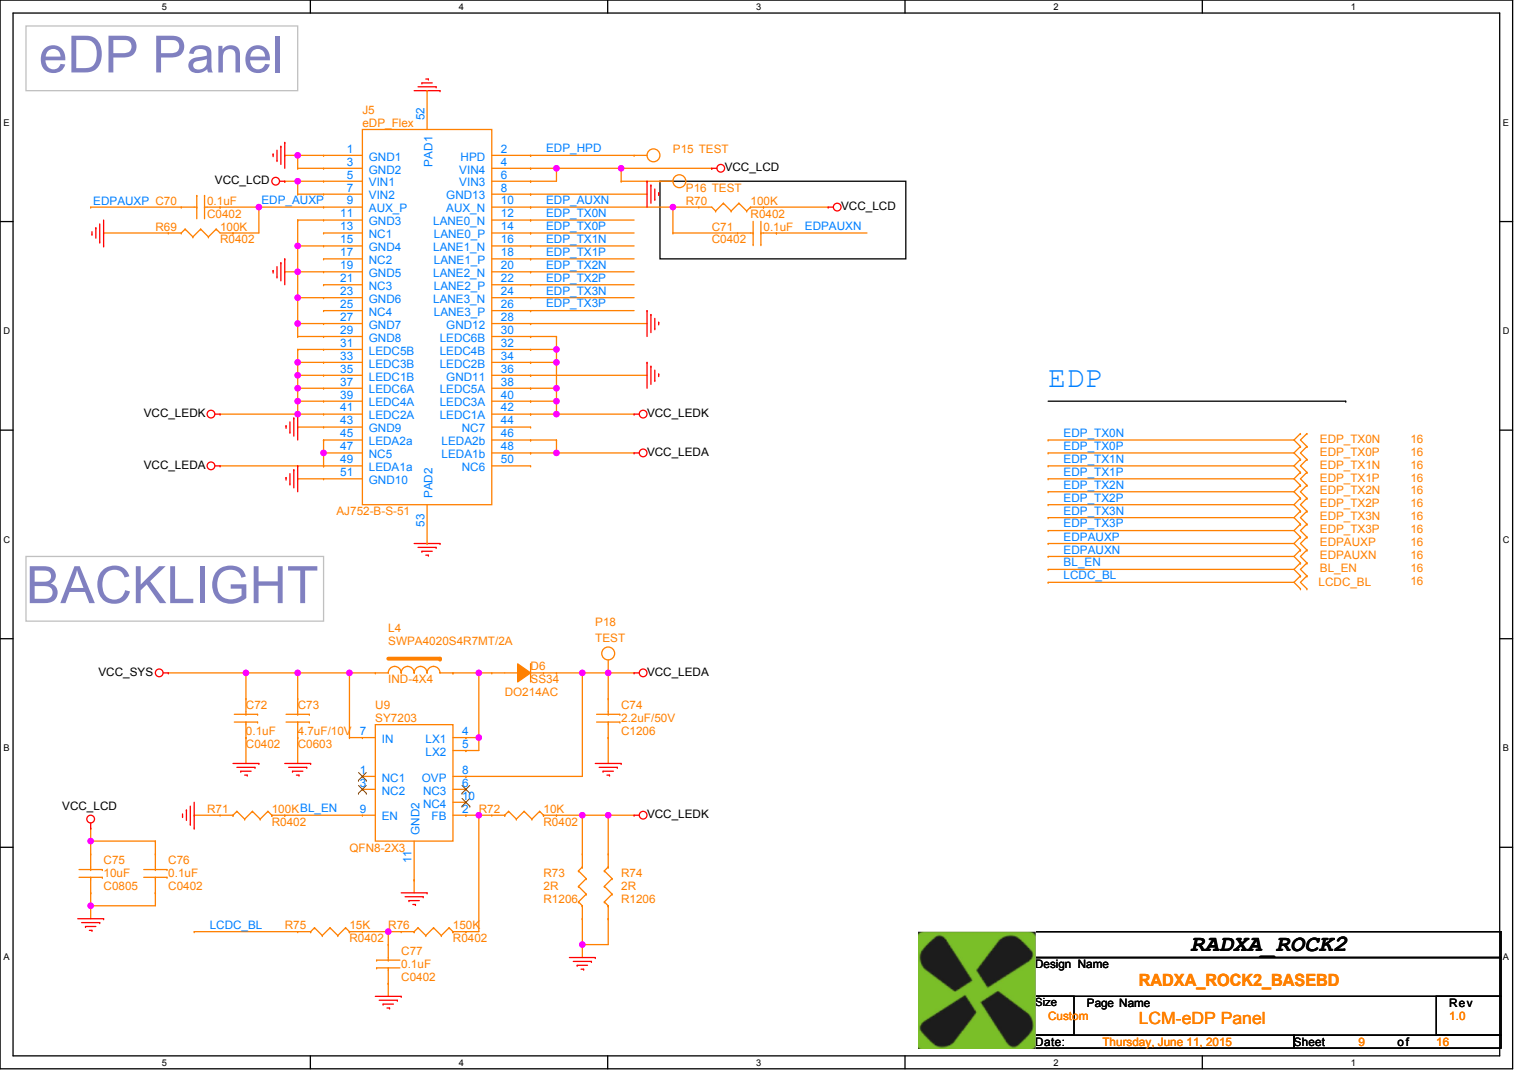
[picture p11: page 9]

# HDMI

## PORT_HPD

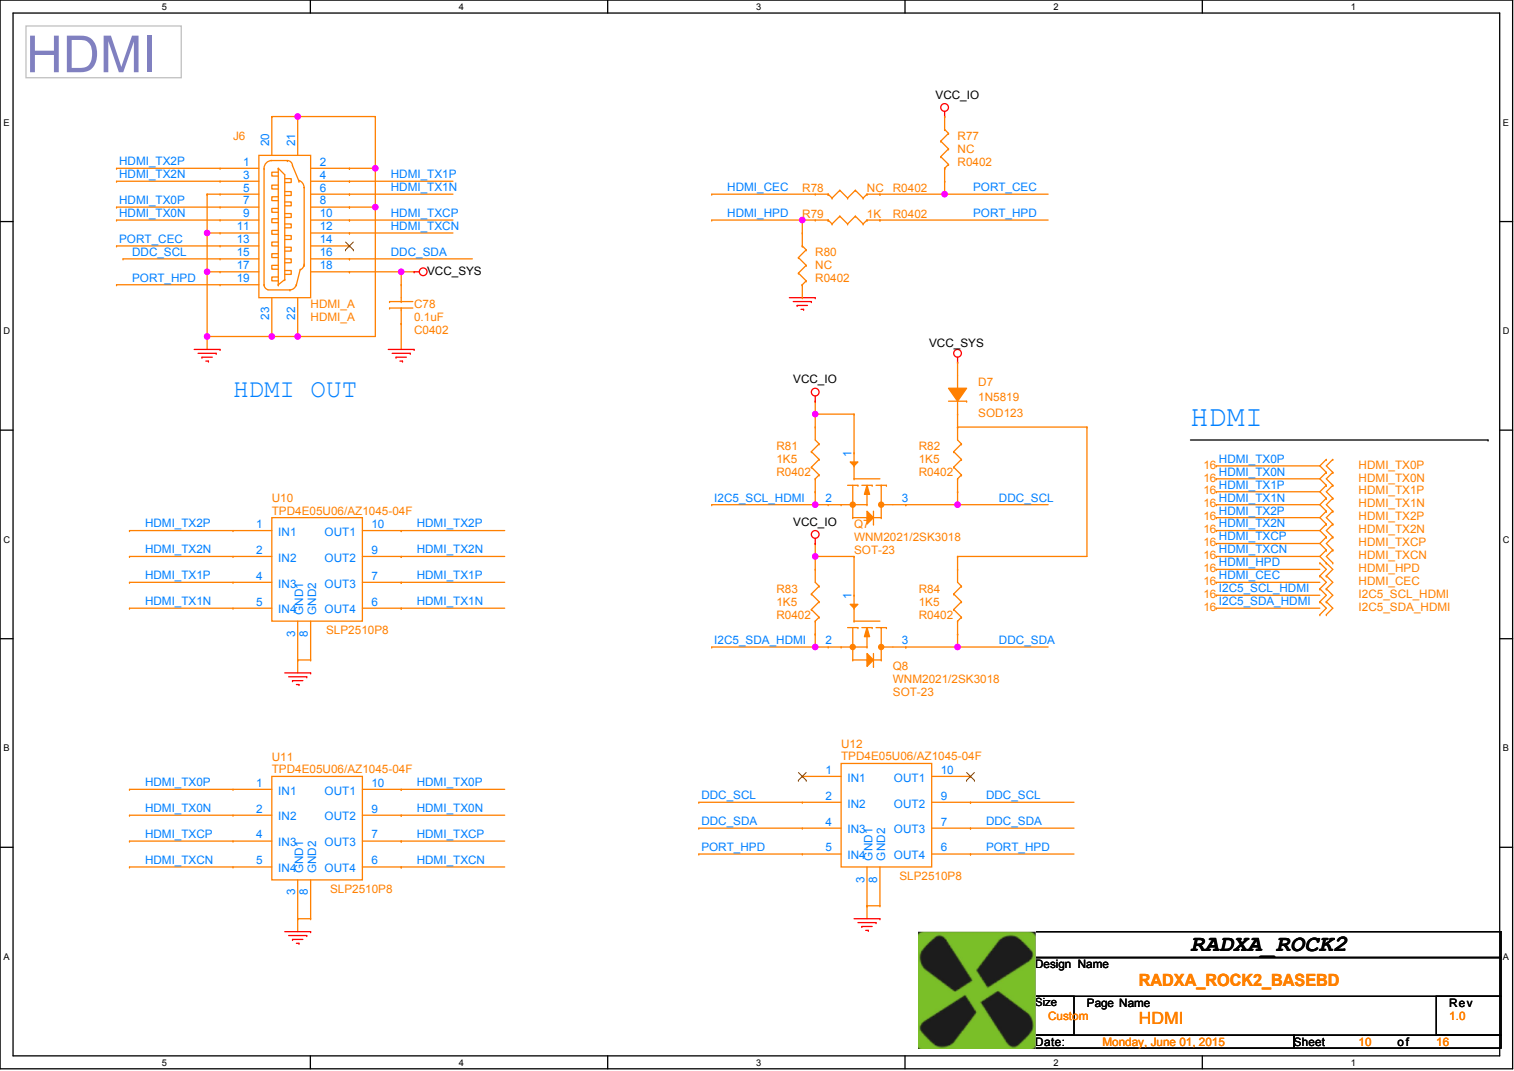
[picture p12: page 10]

# LVDS Panel

# LVDS&MIPI

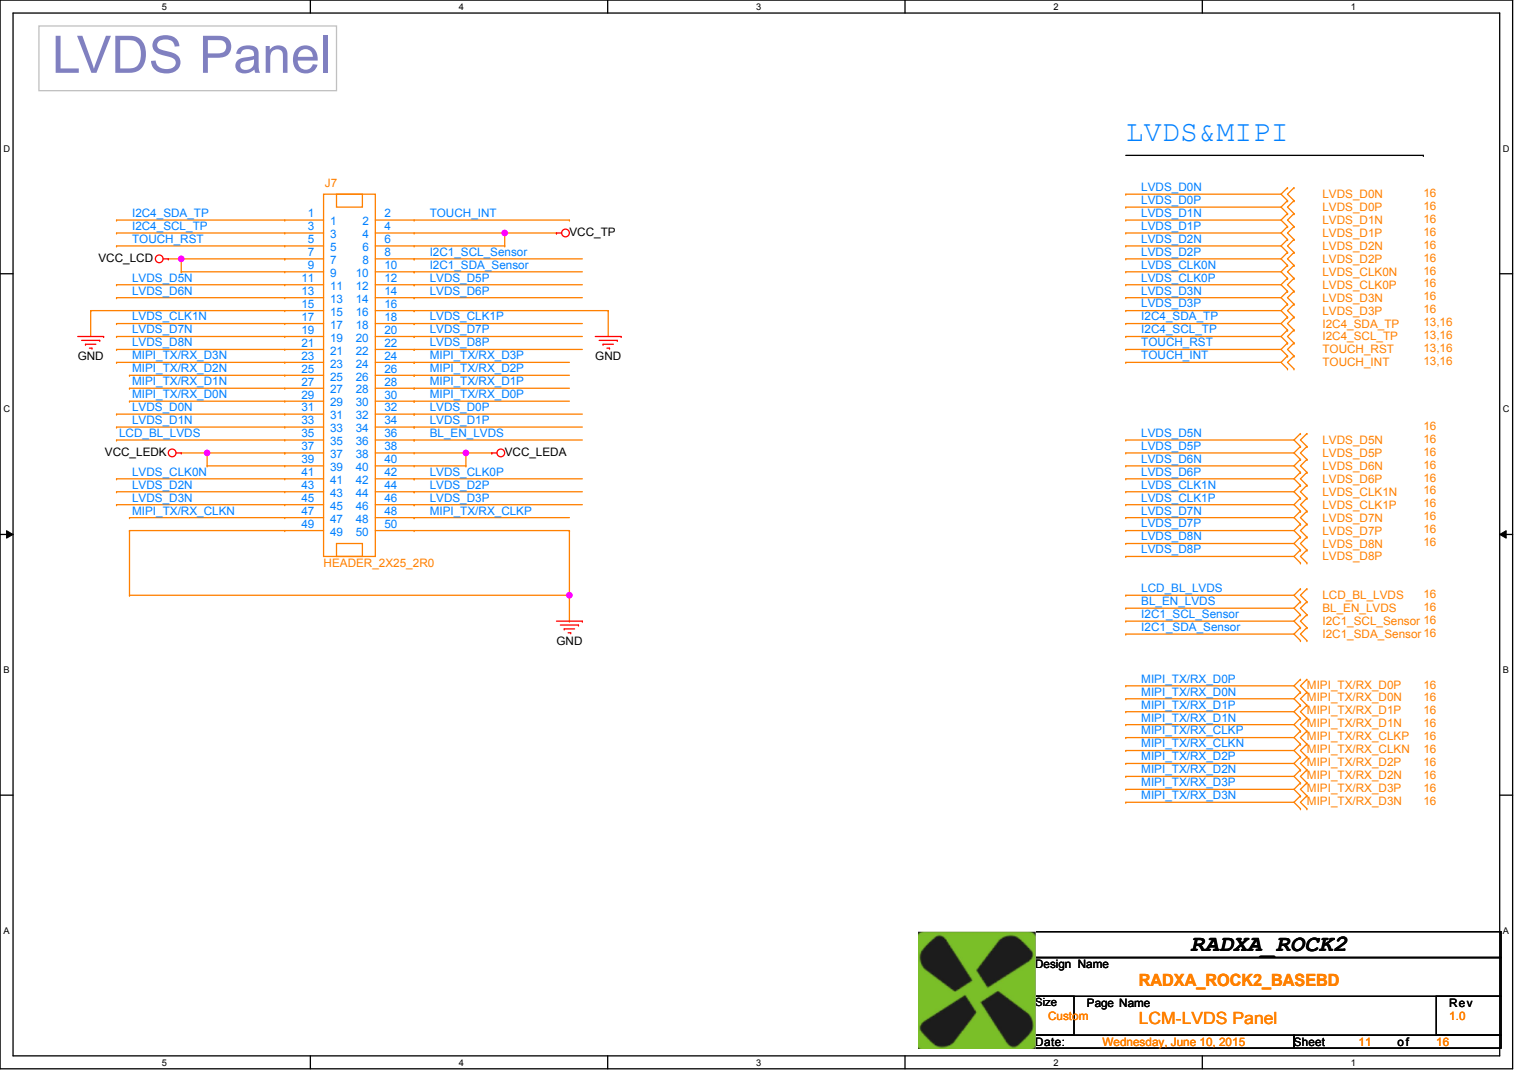
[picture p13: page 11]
I2C1_SDA_Sensor; I2C1_SCL_Sensor; LCD_BL_LVDS BL_EN_LVDS; LVDS_D3N LVDS_D3P; LVDS_D8N; LVDS_D7P; LVDS_D7N; LVDS_D8P; LVDS_CLK0P; LVDS_D2P; LVDS_D2N; LVDS_D1P; LVDS_D1N; LVDS_D0N LVDS_D0P; LVDS_CLK1N LVDS_CLK1P; LVDS_D6P; LVDS_D6N; LVDS_D5P; LVDS_D5N; LVDS_CLK0N; MIPI_TX/RX_D0P; MIPI_TX/RX_D1P; MIPI_TX/RX_D0N; MIPI_TX/RX_D1N MIPI_TX/RX_CLKP MIPI_TX/RX_CLKN; MIPI_TX/RX_D3N; MIPI_TX/RX_D3P; MIPI_TX/RX_D2P MIPI_TX/RX_D2N; I2C1_SCL_Sensor I2C1_SDA_Sensor; MIPI_TX/RX_D2N; MIPI_TX/RX_D2P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

# 50 Ohm RF trace

## Note:

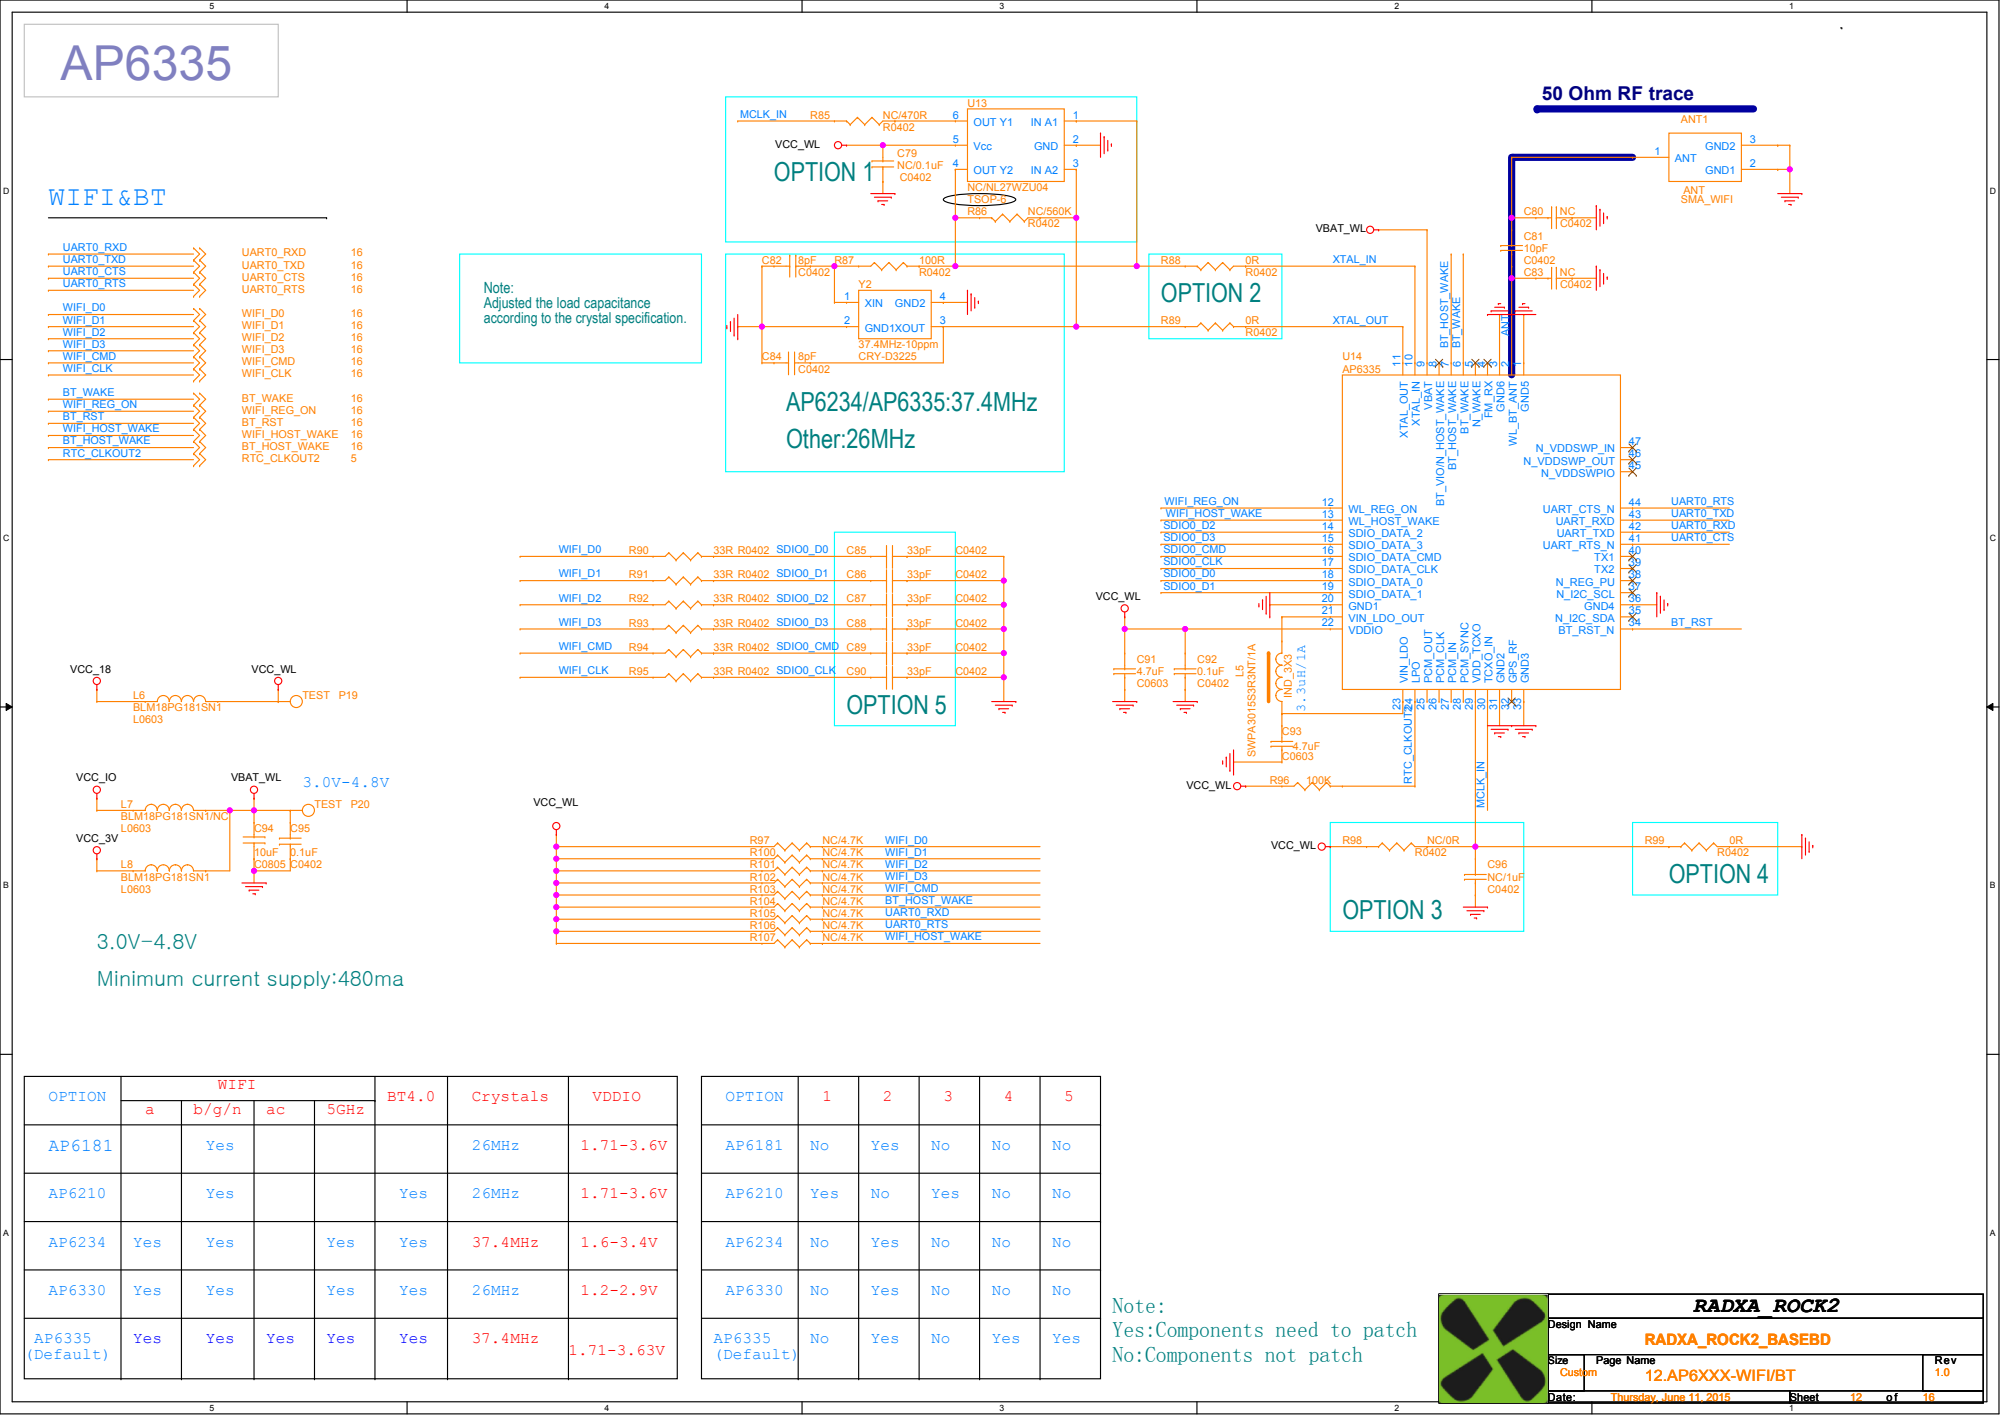
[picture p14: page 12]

Adjusted the load capacitance
according to the crystal specification.

# TP&IR

TP


Pull up on the coreboard

# TF CARD

# TF CARD


## Differential pairs Z0= 100ohm +/-5 ohm


VBUS AVREG AVREG AVREG AVREG

Power On Detection Sequence.
0: Enable USB before detecting attached device.
1: Enable USB after detecting attached device.

In ATA Power Down Mode, GPIO0 should be pull-down.

# MXM-CONNECTOR

# USB


GND GND GND GND

Pull up on the coreboard

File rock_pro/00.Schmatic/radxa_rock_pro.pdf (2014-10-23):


PCB POWER WIRE WIDTH INDICATE


NAND FLASH and iNAND
select one


VDD_JETTA C17 | 225 C0402

VCC18 C18 | 225 C0402

VCCA_33 C19 | 225 C0402

VCC_RMII C21 | 225 C0402

VCCIO_WL C22 | 225 C0402

VCC_18 C24 | 225 C0402




Note:
Place these resisters only used Inand.

note：if use toshiba and sandisk DDR mode，R71 and R74 must be 0R。


Note:
Place these filter capacitors under CPU.


Correspondence between LCDC DATA and RGB

LCDC_D0 | B0 | LCDC_D12 | G4
LCDC_D1 | B1 | LCDC_D13 | G5
LCDC_D2 | B2 | LCDC_D14 | G6
LCDC_D3 | B3 | LCDC_D15 | G7
LCDC_D4 | B4 | LCDC_D16 | R0
LCDC_D5 | B5 | LCDC_D17 | R1



Note: If using other sensor modules,

follow to the requirements of SPEC on the power supply.


2K-5% | R174 4K7-5% MIC_BIAS RADXA_2014 RADXA_2014 RADXA_2014 R0402 | R176

Design Name Design Name Design Name RADXA_2014 RADXA_2014 RADXA_2014 | NC/0R-5% R0402


VDD2A 1 LED2/nINTSEL 2 LED1/REGOFF 3 XTAL2 4 XTAL1/CLKIN 5 VDDCR 6

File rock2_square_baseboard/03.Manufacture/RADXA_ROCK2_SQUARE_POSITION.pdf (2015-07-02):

H1

H4


ANT1ANT1x1 ANT1x3 | ANT1x2 ANT1x4 | ANT1x5

# H1H¹x2H¹x1 H¹x3





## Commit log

2014-10-23 Add schematics, pcb, dxf and manufacturing files
    [RADXA_ROCK_PRO_BOM.xls, radxa_rock_pro.dxf]
2015-07-02 add rock2 square baseboard hardware documents
    [RADXA_ROCK2_SQUARE_VER1.sch, RADXA_ROCK2_SQUARE_beta.dxf, RADXA_ROCK2_SQUAR_BOM_0302.xls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]
